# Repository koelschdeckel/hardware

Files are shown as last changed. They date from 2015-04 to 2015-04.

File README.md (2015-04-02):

Introduction
============

^^dkl is an Open Source hardware project that is being developed in
cooperation between the City of Cologne and Press Any Key UG. The
platform is intended to bridge the gap between devices similar to
Arduino, which allow physical access to sensors via electronic protocols
and device like Raspberry Pi that allow comfortable programming and
access to higher level facilities like Ethernet, USB and Bluetooth at
the cost of system complexity.

The system is intended to be used with applications that require
immediate interaction with the physical world, but need to interact with
the Internet or user devices. Furthermore, technical expertise required
to customise and operate the platform should be reduced to a minimum.

[Find out more](http://koelschdeckel.github.io/)

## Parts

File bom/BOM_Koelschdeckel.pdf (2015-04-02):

BOM # | # Sparrow | Parts sparrow | Type | Value | Shape | Manuf | Model | Alt | Mouser # | DK #

Resistors
| 1 | 4 | R5, R6, R40, R41 | Resistor | 33Ω 1% | 0603 | Samsung | RC1608F330CS | Vishay CRCW060333R0FKEA, Rohm MCR03ERTF33R0 | 71-CRCW0603-33-E3 | 1276-4524-1-ND
| 2 | 4 | R17, R18, R19, R20 | Resistor | 49.9Ω 1% | 0603 | Samsung | RC1608F49R9CS | Vishay CRCW060349R9FKEA | 71-CRCW0603-49.9-E3 | 1276-3505-1-ND
| 3 | 2 | R14, R15 | Resistor | 330Ω | 0603 | Samsung | RC1608J331CS | Yageo RC0603JR-07330RL, Yageo AF0603FR-07330RL, Vishay CRCW0603330RFKEA | 71-CRCW0603-330-E3 | 311-330GRCT-ND
| 4 | 1 | R3 | Resistor | 806Ω | 0603 | Yageo | RC0603FR-07806RL | KOA RK73H1JTTD8060F | 660-RK73H1JTTD8060F | 311-806HRCT-ND
| 5 | 4 | R4, R43, R44, R45 | Resistor | 1K | 0603 | Samsung | RC1608J102CS | Vishay CRCW06031K00FKEA, KOA RK73H1JTTD1001F | 660-RK73H1JTTD1001F | 1276-5062-1-ND
| 6 | 5 | R21, R22, R23, R38, R39 | Resistor | 2.2K | 0603 | Samsung | RC1608J222CS | KOA RK73H1JTTD2201F, Vishay CRCW06032K20FKEA, Yageo RC0603JR-072K2L | 660-RK73H1JTTD2201F | 1276-5070-1-ND
| 7 | 9 | R30, R32, R42, R8, R9, R10, R11, R12, R13 | Resistor | 10K | 0603 | Samsung | RC1608J103CS | Yageo RC0603JR-0710KL, Voshay CRCW060310K0FKEA, KOA RK73H1JTTD1002F | 660-RK73H1JTTD1002F | 1276-5086-1-ND
| 8 | 1 | R7 | Resistor | 12K 1% | 0603 | Samsung | RC1608F123CS | Rohm MCR03ERTF1202, KOA RK73H1JTTD1212F, Vishay CRCW060312K1FKEA | 660-RK73H1JTTD1212F | 1276-4750-1-ND
| 9 | 1 | R16 | Resistor | 12.1K 1% | 0603 | Samsung | RC1608F1212CS | KOA RK73H1JTTD1212F, Vishay CRCW060312K1FKEA, Stackpole RMCF0603FT12K1 | 660-RK73H1JTTD1212F | 1276-4751-1-ND
| 10 | 1 | R26 | Resistor | 40.2K | 0603 | Samsung | RC1608F4022CS | Yageo RC0603FR-0740K2L, KOA RK73H1JTTD4022F, Vishay CRCW060340K2FKEB | 660-RK73H1JTTD4022F | 1276-4800-1-ND
| 11 | 11 | R24, R25, R27, R28, R29, R31, R33, R34, R35, R36, R37 | Resistor | 100K | 0603 | Samsung | RC1608J104CS | Yageo RC0603JR-07100KL, Vishay CRCW0603100KFKEA, KOA RK73H1JTTD1003F | 660-RK73H1JTTD1003F | 1276-5110-1-ND
| 12 | 3 | R1, R46, R47 | Resistor | 768K | 0603 | Yageo | RC0603FR-07768KL | KOA RK73H1JTTD7683F, Rohm MCR03ERTF7683, Vishay CRCW0603768KFKEA | 660-RK73H1JTTD7683F | 311-768KHRCT-ND
| 13 | 1 | R2 | Resistor | 2.4M | 0603 | Samsung | RC1608J245CS | KOA RK73B1JTTD245J, Vishay CRCW06032M40JNEA, Yageo RC0603JR-072M4L | 660-RK73B1JTTD245J | 1276-5143-1-ND

Capacitors

| 14 | 1 | C55 | Capacitor | 2.2p | 0402 | Samsung | CL05C2R2CB5NNNC | Johanson 500R07S2R2DV4T | 609-500R07S2R2DV4T | 1276-1271-1-ND
| 15 | 2 | C68, C69 | Capacitor | 9p | 0402 | Samsung | CL05C090DB5NNNC | Murata GRM1555C1H9R0CA01D | 81-GRM1555C1H9R0CA1D | 1276-1617-1-ND
| 16 | | | Capacitor | 9p | 0603 | Samsung | CL10C090DB8NNNC | TDK C1608C0G1H090C080AA | 810-C1608C0G1H090C | 1276-2143-1-ND
| 17 | 1 | C11 | Capacitor | 10p 5% | 0603 | Samsung | CL10C100JB8NCNC | Vishay VJ0603A100JXACW1BC | 77-VJ0603A100JXACBC | 1276-2154-1-ND
| 18 | 2 | C66, C67 | Capacitor | 12p | 0402 | Samsung | CL05C120JB5NNNC | Johanson 500R07S120KV4T | 609-500R07S120KV4T | 1276-1178-1-ND
| 19 | 4 | C2, C22, C23, C65 | Capacitor | 18p 5% | 0603 | Samsung | CL10C180JC8NNNC | Vishay VJ0603A180JXACW1BC | 77-VJ0603A180JXACBC | 1276-2210-1-ND
| 20 | 1 | C28 | Capacitor | 470p 5% | 0603 | Samsung | CL10C471JB8NCNC | Vishay VJ0603A471JXXCW1BC | 77-VJ0603A471JXXCBC | 1276-2302-1-ND
| 21 | 1 | C1 | Capacitor | 1n | 0402 | Samsung | CL05B102KB5NCNC | KOA X7R0402HTTP102K | 660-X7R0402HTTP102K | 1276-1492-1-ND
| 22 | 1 | C72 | Capacitor | 2.2n | 0402 | Samsung | CL05B222KB5NNNC | Vishay VJ0402Y222KXJCW1BC | 77-VJ0402Y222KXJCBC | 1276-1054-1-ND
| 23 | 3 | C24, C25, C26 | Capacitor | 10n | | Samsung | CL10B103KB8NCNC | Vishay VJ0603Y103KXAAC | 77-VJ0603Y103KXAAC | 1276-1921-1-ND
| 24 | 1 | C61 | Capacitor | 47n | 0402 | Samsung | CL05B473KP5NNNC | Vishay VJ0402Y473KXQCW1BC | 77-VJ0402Y473KXQCBC | 1276-1573-1-ND
| 25 | 3 | C62, C63, C64 | Capacitor | 100n | 0402 | Samsung | CL05A104KP5NNNC | Vishay VJ0402G104MXQPW1BC | 77-VJ0402G104MXQPBC | 1276-1022-1-ND
| 26 | 34 | C3, C4, C5, C6, C7, C12, C13, C14, C15, C16, C17, C18. C19, C20, C21, C30, C31, C32, C33, C34, C35, C36, C37. C38, C39, C43, C45, C47, C49, C54, C58, C70, C74, C75 | Capacitor | 100n | 0603 | Samsung | CL10B104KO8NNNC | Vishay VJ0603Y104JXJPW1BC | 77-VJ0603Y104JXJPBC | 1276-1005-1-ND
| 27 | 9 | C27, C52, C53, C56, C76, C77, C78, C79, C80 | Capacitor | 1u | 0603 | Samsung | CL10B105KP8NNNC | AVX 0603YD105KAT2A | 581-0603YD105K | 1276-1946-1-ND

| 28 | 3 | C8, C9, C10 | Capacitor | 4.7u | 0603 | Samsung | CL10B475KQ8NQNC | Murata GRM188R60J475ME19D | 81-GRM188R60J475ME9D | 1276-2087-1-ND
| 29 | 5 | C29, C42, C44, C46, C48 | Capacitor | 10u | 0603 | Samsung | CL10A106MQ8NNNC | AVX 06036D106MAT2A | 581-06036D106MAT2A | 1276-1119-1-ND
| 30 | 2 | C40, C41 | Capacitor | 22u 6.3V | 0603 | Samsung | CL10A226MQ8NRNC | Murata GRM188R60J226MEA0D, TDK C1608X5R0J226M080AC | 810-C1608X5R0J226M | 1276-1193-1-ND
| 31 | 2 | C57, C59 | Capacitor | 22u 10V | 0805 | Samsung | CL21A226MPQNNNE | TDK C2012X5R1A226M125AB | 810-C2012X5R1A226M-3 | 1276-2910-1-ND
| 32 | 2 | C50, C51 | Capacitor | 47u 6.3V | 0805 | Samsung | CL21A476MQCLRNC | Taiyo Yuden JMK212BJ476MG-T | 963-JMK212BJ476MG-T | 1276-2420-1-ND
| 33 | 1 | C60 | Capacitor | 150u 10V | 1210_POL | AVX | TLNT157M010R1500 | AVX TLJB157M010R0500 | 581-TLNT157M010R | 478-3349-1-ND

Inductors
| 34 | 1 | L5 | Inductor | 2.2n | 0402 | Taiyo Yuden | HK10052N2S-T | Taiyo Yuden HK10052N2S-T, Panasonic ELJ-RF2N2ZFB, TDK MLG1005S2N2S | 963-HK10052N2S-T | 587-1503-1-ND
| 35 | 1 | L7 | Inductor | 2.2u 2.2Arms, 3A sat | 40x40 | Laird | TYS40302R2N-10 | Bourns SRN4018-2R2M, Taiyo Yuden NRS4018T2R2MDGJ | 963-NRS4018T2R2MDGJ | 240-2697-1-ND
| 36 | 1 | L1 | Inductor | 10u 1A | 40x40 | Taiyo Yuden | NRS4018T100MDGJ | | 963-NRS4018T100MDGJ | 587-2886-1-ND

Diodes
| 37 | 5 | D1, D2, D3, D4, D5 | Diode | 2A 30V Schottky | SOD123/ SOD123FL | ON Semi | MBR230LSFT1 | Comchip CDBMT240-HF | 863-MBR230LSFT1G | MBR230LSFT1GOSCT-ND

LEDs
| 38 | 4 | LED1, LED2, LED3, LED4 | LED | any color, 100mcd min | 0603_POL | Vishay | VLMY1300-GS08 (yellow) | Osram LS Q976-NR-1 | 78-VLMY1300-GS08 | 475-2512-1-ND

ICs

| 39 | 1 | IC1 | IC | LAN8720A | QFN24-0.5 | SMSC/Microchip | LAN8720A/ LAN8720AI | | 886-LAN8720A-CP | LAN8720A-CP-CT-ND
| 40 | 1 | IC2 | IC | TLV320AIC3100 | QFN32-0.5 | TI | TLV320AIC3100IRHBR/T | | 595-V320AIC3100IRHBT | 296-25494-1-ND
| 41 | 1 | IC3 | IC | TPS2500 | SON10-0.5 | TI | TPS2500DRCT | | 595-TPS2500DRCT | 296-32462-1-ND
| 42 | 5 | IC4, IC5, IC6, IC7, IC8 | IC | AAT4280A | SC70JW-8 | Skyworks | AAT4280A | | 873-AAT4280AIJS-2-T1 | 863-1480-1-ND
| 43 | 1 | IC9 | IC | FXMA108 | DFN20 | Fairchild | FXMA108 | | 512-FXMA108BQX | FXMA108BQXFSCT-ND
| 44 | 1 | MCU | IC | NXP1837 | QFP144-0.5 | NXP | LPC1837JBD144E | | 771-LPC1837JBD144E | LPC1837JBD144E-ND
| 45 | 1 | MCU1 | IC | NRF51822 | QFN48-0.4 | Nordic Semi | NRF51822QFAA | | 949-NRF51822-QFAA-R7
| 46 | | | IC | PN532 | QFN40 | NXP | PN5321A3HN/C106;55 | | 771-PN5321A3HNC106 | 568-8600-ND
| 47 | 1 | PWR1 | IC | LTC4080 | DFN10 | Linear | LTC4080 | LTC4081 | | LTC4081EDD#PBF-ND

Modules

| 48 | 1 | WIFI | Module | CC3000 | | TI | CC3000MOD | | 595-CC3000MOD | 296-35512-1-ND

Clocks
| 49 | 2 | X1, X3 | Crystal | 32.768KHz 12.5pF | 1206 | Abracon | ABS07 | TXC 9HT10-32.768KAZF-T, Citizen CM315D32768DZFT | 717-9HT10-32.768KAZF | 300-8814-1-ND
| 50 | 1 | X2 | Crystal | 12MHz 10pF 40ppm | 3.2 x 2.5 | AVX | CX3225GB12000P0HPQC C | ABM8G-12.000MHZ-4Y-T3 | 581-CX3225GB12PHPQCC | 535-10901-1-ND
| 51 | 1 | X5 | Crystal | 16MHz 8pF 40ppm | 2.5 x 2.0 | AVX | CX2520DB16000D0GEJC C | | 581-CX2520DB16DGEJCC | 1253-1122-1-ND
| 52 | | | Crystal | 27.12MHz 10pF 20ppm | 5 x 3.2 | TXC | 7B-27.120MEEQ-T | | | 887-1309-1-ND
| 53 | 1 | X4 | Oscillator | 50MHz | 2.5 x 2.0 | SiLabs | 501AAA50M0000DAG | SITime SiT8103AI-13-33E-50.00000X | 788-8103I-333E50X | 336-2981-ND

RF

| 54 | 2 | ANT1, ANT2 | Antenna | 2.4GHz | 1206 | Abracon | AMCA31-2R450G-S1F | | 815-CA312R450GS1FT | 535-12386-1-ND
| 55 | 1 | BAL1 | Balun | for NRF51822 | WLCSP5 | ST | BALF-NRF01D3 | BAL-NRF01D3 (worse) | 511-BAL-NRF01D3 | 497-13637-1-ND

Mechanical

| 56 | 2 | !PGM, RESET | Button | CK-KMR2 | | CK | KMR2xx | | 611-KMR211G-LFS | CKN10272CT-ND
| 57 | 1 | 5VDC_IN | Connector | Barrel 5.5/2.1 2A | | CUI | PJ 102AH | | | CP-102AH-ND
| 58 | 1 | BATT | Connector | 2mm LiPo/Li-Ion | | JST | PH-H | | | 455-1749-1-ND
| 59 | 1 | ETH | Connector | RJ45-Mag-LEDs | | WIZnet | RB1-125BAG1A | | 950-RB1-125BAG1A | 1278-1011-ND
| 60 | 1 | HEADPHONE | Connector | 3.5mm stereo | | CUI | SJ 3523 | Switchcraft 35RASMT2BHNTRX | 502-35RASMT2BHNTRX | CP-3523SJCT-ND

61 | 1 | SD_CARD | Connector | SD card holder | Amphenol | 101_00313 | 523-101-00313-68-02
62 | 1 | USB1 | Connector | Micro USB-B | FCI | 10104110-0001LF | 649-10104110-0001LF
63 | 1 | USB0 | Connector | Micro USB-AB | FCI | 10104111-0001LF | 649-10104111-0001LF

ARM DEBUGs

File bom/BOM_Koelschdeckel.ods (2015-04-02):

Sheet: Tabelle1
Order Master |  | 5
Order NFC |  | 5
Category | BOM # | # Sparrow | # NFC | Parts sparrow | check | Parts NFC | check | Type | Value | Shape | # needed | # have | Manuf | Model | Alt | Mouser # | Mouser € | Mouser @ | DK # | DK € | DK @ | Schukat # | Schukat € | Schukat @ | Order source | Order # | Ordered | Mouser € | DK € | Schukat € | Remarks | Received | € per sparrow |  | Mouser order table | Mouser order table | DK order table | DK order table
Resistors
 | 1 |  | 2 |  | ✓ | R17,R18 | ✓ | Resistor | 1.5Ω | 0603 | 10 |  | Samsung | RC1608J1R5CS | KOA RK73H1JTTD1R50F, Yageo RC0603JR-071R5L | 660-RK73H1JTTD1R50F | 0,006 | 100 | 1276-4994-1-ND | 0,0036 | 100 |  |  |  | DK | 100 | DK + |  | 0,36 |  |  | ✓ | 0 | 0,0072 |  |  | 100 | 1276-4994-1-ND
 | 2 | 4 |  | R5, R6, R40, R41 | ✓ |  | ✓ | Resistor | 33Ω 1% | 0603 | 20 | yeah! | Samsung | RC1608F330CS | Vishay CRCW060333R0FKEA, Rohm MCR03ERTF33R0 | 71-CRCW0603-33-E3 | 0,008 | 100 | 1276-4524-1-ND | 0,0046 | 100 |  |  |  | DK | 100 | Bestand |  | 0,46 |  |  | (✓) | 0,0184 | 0
 | 3 | 4 |  | R17, R18, R19, R20 | ✓ |  | ✓ | Resistor | 49.9Ω 1% | 0603 | 20 |  | Samsung | RC1608F49R9CS | Vishay CRCW060349R9FKEA | 71-CRCW0603-49.9-E3 | 0,008 | 100 | 1276-3505-1-ND | 0,0046 | 100 |  |  |  | DK | 100 | DK + |  | 0,46 |  |  | ✓ | 0,0184 | 0 |  |  | 100 | 1276-3505-1-ND
 | 4 | 2 |  | R14, R15 | ✓ |  | ✓ | Resistor | 330Ω | 0603 | 10 |  | Samsung | RC1608J331CS | Yageo RC0603JR-07330RL, Yageo AF0603FR-07330RL, Vishay CRCW0603330RFKEA | 71-CRCW0603-330-E3 | 0,008 | 100 | 311-330GRCT-ND | 0,0036 | 100 |  |  |  | DK | 100 | DK + |  | 0,36 |  |  | ✓ | 0,0072 | 0 |  |  | 100 | 311-330GRCT-ND
 | 5 | 1 | 1 | R3 | ✓ | R3 | ✓ | Resistor | 806Ω | 0603 | 10 |  | Yageo | RC0603FR-07806RL | KOA RK73H1JTTD8060F | 660-RK73H1JTTD8060F | 0,006 | 100 | 311-806HRCT-ND | 0,0046 | 100 |  |  |  | DK | 100 | DK + |  | 0,46 |  |  | ✓ | 0,0046 | 0,0046 |  |  | 100 | 311-806HRCT-ND
 | 6 | 4 | 6 | R4, R43, R44, R45 | ✓ | R4, R13, R14, R15, R19, R21 | ✓ | Resistor | 1K | 0603 | 50 |  | Samsung | RC1608J102CS | Vishay CRCW06031K00FKEA, KOA RK73H1JTTD1001F | 660-RK73H1JTTD1001F | 0,006 | 100 | 1276-5062-1-ND | 0,0036 | 100 | RL0603K001-1 | 0,00119 | 5000 | Schukat | 5000 | Schukat |  |  | 5,95 | Digikey ist pro Rolle günstiger als Schukat, aber Schukat hat 1% statt 5% Toleranz | ✓ | 0,00476 | 0,00714
 | 7 |  | 1 |  | ✓ | R16 | ✓ | Resistor | 1.6K | 0603 | 5 |  | Samsung | RC1608J162CS | KOA RK73H1JTTD1601F, Vishay CRCW06031K60FKEA, Yageo RC0603JR-071K6L | 660-RK73H1JTTD1601F | 0,006 | 100 | 1276-5067-1-ND | 0,0036 | 100 |  |  |  | DK | 100 | DK + |  | 0,36 |  |  | ✓ | 0 | 0,0036 |  |  | 100 | 1276-5067-1-ND
 | 8 |  | 3 |  | ✓ | R10, R11, R16 | ✓ | Resistor | 2K | 0603 | 15 |  | Samsung | RC1608J202CS | Vishay CRCW06032K00FKEA, KOA RK73H1JTTD2001F, Yageo RC0603JR-072KL | 660-RK73H1JTTD2001F | 0,006 | 100 | 1276-5069-1-ND | 0,0036 | 100 |  |  |  | DK | 100 | DK + |  | 0,36 |  |  | ✓ | 0 | 0,0108 |  |  | 100 | 1276-5069-1-ND
 | 9 | 5 |  | R21, R22, R23, R38, R39 | ✓ |  | ✓ | Resistor | 2.2K | 0603 | 25 |  | Samsung | RC1608J222CS | KOA RK73H1JTTD2201F, Vishay CRCW06032K20FKEA, Yageo RC0603JR-072K2L | 660-RK73H1JTTD2201F | 0,006 | 100 | 1276-5070-1-ND | 0,0036 | 100 | RL0603K002.2-1 | 0,00119 | 5000 | Schukat | 5000 | Schukat |  |  | 5,95 |  | ✓ | 0,00595 | 0
 | 10 | 9 | 6 | R30, R32, R42, R8, R9, R10, R11, R12, R13 | ✓ | R5, R6, R7, R9, R12, R34 | ✓ | Resistor | 10K | 0603 | 75 | yeah! | Samsung | RC1608J103CS | Yageo RC0603JR-0710KL, Voshay CRCW060310K0FKEA, KOA RK73H1JTTD1002F | 660-RK73H1JTTD1002F | 0,006 | 100 | 1276-5086-1-ND | 0,0036 | 100 | RL0603K010-1 | 0,00119 | 5000 | Schukat | 5000 | Bestand |  |  | 5,95 |  | (✓) | 0,01071 | 0,00714
 | 11 | 1 |  | R7 | ✓ |  | ✓ | Resistor | 12K 1% | 0603 | 5 |  | Samsung | RC1608F123CS | Rohm MCR03ERTF1202, KOA RK73H1JTTD1212F, Vishay CRCW060312K1FKEA | 660-RK73H1JTTD1212F | 0,006 | 100 | 1276-4750-1-ND | 0,0046 | 100 |  |  |  | DK | 100 | DK + |  | 0,46 |  |  | ✓ | 0,0046 | 0 |  |  | 100 | 1276-4750-1-ND
 | 12 | 1 |  | R16 | ✓ |  | ✓ | Resistor | 12.1K 1% | 0603 | 5 |  | Samsung | RC1608F1212CS | KOA RK73H1JTTD1212F, Vishay CRCW060312K1FKEA, Stackpole RMCF0603FT12K1 | 660-RK73H1JTTD1212F | 0,006 | 100 | 1276-4751-1-ND | 0,0046 | 100 |  |  |  | DK | 100 | DK + |  | 0,46 |  |  | ✓ | 0,0046 | 0 |  |  | 100 | 1276-4751-1-ND
 | 13 | 1 |  | R26 | ✓ |  | ✓ | Resistor | 40.2K | 0603 | 5 |  | Samsung | RC1608F4022CS | Yageo RC0603FR-0740K2L, KOA RK73H1JTTD4022F, Vishay CRCW060340K2FKEB | 660-RK73H1JTTD4022F | 0,006 | 100 | 1276-4800-1-ND | 0,0046 | 100 |  |  |  | DK | 100 | DK + |  | 0,46 |  |  | ✓ | 0,0046 | 0 |  |  | 100 | 1276-4800-1-ND
 | 14 | 11 |  | R24, R25, R27, R28, R29, R31, R33, R34, R35, R36, R37 | ✓ |  | ✓ | Resistor | 100K | 0603 | 55 |  | Samsung | RC1608J104CS | Yageo RC0603JR-07100KL, Vishay CRCW0603100KFKEA, KOA RK73H1JTTD1003F | 660-RK73H1JTTD1003F | 0,006 | 100 | 1276-5110-1-ND | 0,0036 | 100 | RL0603K100-1 | 0,00119 | 5000 | Schukat | 5000 | Schukat |  |  | 5,95 |  | ✓ | 0,01309 | 0
 | 15 | 3 | 1 | R1, R46, R47 | ✓ | R1 | ✓ | Resistor | 768K | 0603 | 20 |  | Yageo | RC0603FR-07768KL | KOA RK73H1JTTD7683F, Rohm MCR03ERTF7683, Vishay CRCW0603768KFKEA | 660-RK73H1JTTD7683F | 0,006 | 100 | 311-768KHRCT-ND | 0,0048 | 100 |  |  |  | DK | 100 | DK + |  | 0,48 |  |  | ✓ | 0,0144 | 0,0048 |  |  | 100 | 311-768KHRCT-ND
 | 16 | 1 | 1 | R2 | ✓ | R2 | ✓ | Resistor | 2.4M | 0603 | 10 |  | Samsung | RC1608J245CS | KOA RK73B1JTTD245J, Vishay CRCW06032M40JNEA, Yageo RC0603JR-072M4L | 660-RK73B1JTTD245J | 0,003 | 100 | 1276-5143-1-ND | 0,0036 | 100 |  |  |  | Mouser | 100 | Mouser + | 0,3 |  |  |  | ✓ | 0,003 | 0,003 | 100 | 660-RK73B1JTTD245J
Capacitors |  |  |  |  |  |  | ✓ |  |  |  |  |  |  |  |  |  |  |  |  |  |  |  |  |  |  |  |  |  |  |  |  |  | 0 | 0
 | 17 | 1 |  | C55 | ✓ |  | ✓ | Capacitor | 2.2p | 0402 | 5 |  | Samsung | CL05C2R2CB5NNNC | Johanson 500R07S2R2DV4T | 609-500R07S2R2DV4T | 0,016 | 1 | 1276-1271-1-ND | 0,0062 | 100 |  |  |  | DK | 100 | DK + |  | 0,62 |  |  | ✓ | 0,0062 | 0 |  |  | 100 | 1276-1271-1-ND
 | 18 | 2 |  | C68, C69 | ✓ |  | ✓ | Capacitor | 9p | 0402 | 10 |  | Samsung | CL05C090DB5NNNC | Murata GRM1555C1H9R0CA01D | 81-GRM1555C1H9R0CA1D | 0,008 | 100 | 1276-1617-1-ND | 0,0076 | 100 |  |  |  | DK | 100 | DK + |  | 0,76 |  |  | ✓ | 0,0152 | 0 |  |  | 100 | 1276-1617-1-ND
 | 19 |  | 2 |  |  | C68, C69 | ✓ | Capacitor | 9p | 0603 | 10 |  | Samsung | CL10C090DB8NNNC | TDK C1608C0G1H090C080AA | 810-C1608C0G1H090C | 0,01 | 100 | 1276-2143-1-ND | 0,0153 | 100 |  |  |  | Mouser | 100 | Mouser + | 1 |  |  |  | ✓ | 0 | 0,02 | 100 | 810-C1608C0G1H090C
 | 20 | 1 | 3 | C11 | ✓ | C11, C31, C39 | ✓ | Capacitor | 10p 5% | 0603 | 20 |  | Samsung | CL10C100JB8NCNC | Vishay VJ0603A100JXACW1BC | 77-VJ0603A100JXACBC | 0,032 | 100 | 1276-2154-1-ND | 0,0036 | 100 |  |  |  | DK | 100 | DK + |  | 0,36 |  |  | ✓ | 0,0036 | 0,0108 |  |  | 100 | 1276-2154-1-ND
 | 21 | 2 |  | C66, C67 | ✓ |  | ✓ | Capacitor | 12p | 0402 | 10 | yeah! | Samsung | CL05C120JB5NNNC | Johanson 500R07S120KV4T | 609-500R07S120KV4T | 0,016 | 1 | 1276-1178-1-ND | 0,0047 | 100 |  |  |  | DK | 100 | Bestand |  | 0,47 |  |  | (✓) | 0,0094 | 0
 | 22 |  | 6 |  | ✓ | C1, C2, C22, C23, C66, C67 | ? | Capacitor | 12p 5% | 0603 | 30 |  | Samsung | CL10C120JC8NNNC | Vishay VJ0603A120JXACW1BC | 77-VJ0603A120JXACBC | 0,032 | 100 | 1276-2177-1-ND | 0,0091 | 100 |  |  |  | DK | 100 | DK + |  | 0,91 |  |  | ✓ | 0 | 0,0546 |  |  | 100 | 1276-2177-1-ND
 | 23 |  | 4 |  | ✓ | C1, C2, C22, C23, C66, C67 | ? | Capacitor | 16p 5% | 0603 | 20 |  | Samsung | CL10C160JB8NNNC | Murata GCM1885C2A160JA16D | 81-GCM1885C2A160JA6D | 0,02 | 100 | 1276-2204-1-ND | 0,02450 | 100 |  |  |  | DK | 100 | DK + |  | 2,45 |  |  | ✓ | 0 | 0,098 |  |  | 100 | 1276-2204-1-ND
 | 24 | 4 |  | C2, C22, C23, C65 | ✓ |  | ✓ | Capacitor | 18p 5% | 0603 | 20 | yeah! | Samsung | CL10C180JC8NNNC | Vishay VJ0603A180JXACW1BC | 77-VJ0603A180JXACBC | 0,032 | 100 | 1276-2210-1-ND | 0,0072 | 100 |  |  |  | DK | 100 | Bestand |  | 0,72 |  |  | (✓) | 0,0288 | 0
 | 25 |  | 2 |  | ✓ | C45, C48 | ✓ | Capacitor | 22p 5% | 0603 | 10 |  | Samsung | CL10C220JB8NCNC | Vishay VJ0603A220JXACW1BC, TDK C1608C0G1H220J080AA | 77-VJ0603A220JXACBC | 0,032 | 100 | 1276-2227-1-ND | 0,0036 | 100 |  |  |  | DK | 100 | DK + |  | 0,36 |  | Ersatzmodell bestellt | ✓ | 0 | 0,0072 |  |  | 100 | 1276-2227-1-ND
 | 26 |  | 1 |  | ✓ | C37 | ✓ | Capacitor | 27p 5% | 0603 | 5 |  | Samsung | CL10C270JB8NCNC | Vishay VJ0603A270JXACW1BC | 77-VJ0603A270JXACBC | 0,032 | 100 | 1276-2248-1-ND | 0,0036 | 100 |  |  |  | DK | 100 | DK + |  | 0,36 |  |  | ✓ | 0 | 0,0036 |  |  | 100 | 1276-2248-1-ND
 | 27 |  | 2 |  | ✓ | C37, C38 | ✓ | Capacitor | 47p 5% | 0603 | 10 |  | Samsung | CL10C470JB8NCNC | Vishay VJ0603A470JXACW1BC | 77-VJ0603A470JXACBC | 0,032 | 100 | 1276-2296-1-ND | 0,0049 | 100 |  |  |  | DK | 100 | DK + |  | 0,49 |  |  | ✓ | 0 | 0,0098 |  |  | 100 | 1276-2296-1-ND
 | 28 |  | 1 |  | ✓ | C44 | ✓ | Capacitor | 56p 5% | 0603 | 5 |  | Samsung | CL10C560JB8NNNC | Vishay VJ0603A560JXACW1BC | 77-VJ0603A560JXACBC | 0,032 | 100 | 1276-1197-1-ND | 0,0092 | 100 |  |  |  | DK | 100 | DK + |  | 0,92 |  |  | ✓ | 0 | 0,0092 |  |  | 100 | 1276-1197-1-ND
 | 29 |  | 3 |  | ✓ | C34, C43, C50 | ✓ | Capacitor | 100p 5% | 0603 | 15 |  | Samsung | CL10C101JB8NCNC | Vishay VJ0603A101JXACW1BC | 77-VJ0603A101JXACBC | 0,032 | 100 | 1276-2163-1-ND | 0,0036 | 100 |  |  |  | DK | 100 | DK + |  | 0,36 |  |  | ✓ | 0 | 0,0108 |  |  | 100 | 1276-2163-1-ND
 | 30 |  | 3 |  | ✓ | C32, C46, C47 | ✓ | Capacitor | 220p 5% | 0603 | 15 |  | Samsung | CL10C221JB8NCNC | Vishay VJ0603A221JXBPW1BC | 77-VJ0603A221JXBPBC | 0,01 | 100 | 1276-2234-1-ND | 0,0049 | 100 |  |  |  | DK | 100 | DK + |  | 0,49 |  | Ersatzmodell bestellt | ✓ | 0 | 0,0147 |  |  | 100 | 1276-2234-1-ND
 | 31 | 1 |  | C28 | ✓ |  | ✓ | Capacitor | 470p 5% | 0603 | 5 |  | Samsung | CL10C471JB8NCNC | Vishay VJ0603A471JXXCW1BC | 77-VJ0603A471JXXCBC | 0,018 | 100 | 1276-2302-1-ND | 0,01210 | 100 |  |  |  | DK | 100 | DK + |  | 1,21 |  | Ersatzmodell bestellt | ✓ | 0,0121 | 0 |  |  | 100 | 1276-2302-1-ND
 | 32 |  | 2 |  | ✓ | C30, C33 | ✓ | Capacitor | 680p 5% | 0603 | 10 |  | Samsung | CL10C681JB8NFNC | Vishay VJ0603Y681JXBCW1BC | 77-VJ0603Y681JXBCBC | 0,025 | 100 | 1276-2329-1-ND | 0,01210 | 100 |  |  |  | DK | 100 | DK + |  | 1,21 |  |  | ✓ | 0 | 0,0242 |  |  | 100 | 1276-2329-1-ND
 | 33 | 1 | 1 | C1 | ✓ | C65 | ✓ | Capacitor | 1n | 0402 | 10 | yeah! | Samsung | CL05B102KB5NCNC | KOA X7R0402HTTP102K | 660-X7R0402HTTP102K | 0,008 | 1 | 1276-1492-1-ND | 0,0041 | 100 |  |  |  | DK | 100 | Bestand |  | 0,41 |  |  | (✓) | 0,0041 | 0,0041
 | 34 |  | 1 |  | ✓ | C42 | ✓ | Capacitor | 1n 5% | 0603 | 5 |  | Samsung | CL10C102JB8NNNC | Vishay VJ0603Y102JXBCW1BC | 77-VJ0603Y102JXBCBC | 0,025 | 100 | 1276-1091-1-ND | 0,01260 | 100 |  |  |  | DK | 100 | DK + |  | 1,26 |  |  | ✓ | 0 | 0,0126 |  |  | 100 | 1276-1091-1-ND
 | 35 |  | 2 |  | ✓ | C28, C29 | ✓ | Capacitor | 1.2n 5% | 0603 | 10 |  | Samsung | CL10C122JB8NNNC | Murata GRM1885C1E122JA01D | 81-GRM1885C1E122JA1D | 0,022 | 100 | 1276-2184-1-ND | 0,0306 | 100 |  |  |  | Mouser | 100 | Mouser + | 2,2 |  |  |  | ✓ | 0 | 0,044 | 100 | 81-GRM1885C1E122JA1D
 | 36 |  | 2 |  | ✓ | C26, C27 | ✓ | Capacitor | 1.5n 5% | 0603 | 10 |  | Samsung | CL10C152JB8NNNC | Vishay VJ0603Y152JXAAC | 77-VJ0603Y152JXAAC | 0,023 | 100 | 1276-2203-1-ND | 0,0298 | 100 |  |  |  | Mouser | 100 | Mouser + | 2,3 |  |  |  | ✓ | 0 | 0,046 | 100 | 77-VJ0603Y152JXAAC
 | 37 | 1 | 1 | C72 | ✓ | C72 | ✓ | Capacitor | 2.2n | 0402 | 10 | yeah! | Samsung | CL05B222KB5NNNC | Vishay VJ0402Y222KXJCW1BC | 77-VJ0402Y222KXJCBC | 0,026 | 100 | 1276-1054-1-ND | 0,0052 | 100 |  |  |  | DK | 100 | Bestand |  | 0,52 |  |  | (✓) | 0,0052 | 0,0052
 | 38 | 3 | 5 | C24, C25, C26 | ✓ | C3, C7, C13, C15, C17 | ✓ | Capacitor | 10n |  | 40 |  | Samsung | CL10B103KB8NCNC | Vishay VJ0603Y103KXAAC | 77-VJ0603Y103KXAAC | 0,024 | 100 | 1276-1921-1-ND | 0,0036 | 100 | CL10B103KB8NNNC | 0,0014 | 4000 | Schukat | 4000 | Schukat |  |  | 5,6 |  | ✓ | 0,0042 | 0,007
 | 39 | 1 | 1 | C61 | ✓ | C61 | ✓ | Capacitor | 47n | 0402 | 10 | yeah! | Samsung | CL05B473KP5NNNC | Vishay VJ0402Y473KXQCW1BC | 77-VJ0402Y473KXQCBC | 0,046 | 100 | 1276-1573-1-ND | 0,0052 | 100 |  |  |  | Mouser | 100 | Bestand | 4,6 |  |  |  | (✓) | 0,046 | 0,046
 | 40 | 3 |  | C62, C63, C64 | ✓ |  | ✓ | Capacitor | 100n | 0402 | 15 | yeah! | Samsung | CL05A104KP5NNNC | Vishay VJ0402G104MXQPW1BC | 77-VJ0402G104MXQPBC | 0,046 | 100 | 1276-1022-1-ND | 0,0044 | 100 |  |  |  | DK | 100 | Bestand |  | 0,44 |  |  | (✓) | 0,0132 | 0
 | 41 | 34 | 11 | C3, C4, C5, C6, C7, C12, C13, C14, C15, C16, C17, C18. C19, C20, C21, C30, C31, C32, C33, C34, C35, C36, C37. C38, C39, C43, C45, C47, C49, C54, C58, C70, C74, C75 | ✓ | C5, C19, C20, C21, C24, C35, C36, C41, C62, C63, C64 | ✓ | Capacitor | 100n | 0603 | 225 |  | Samsung | CL10B104KO8NNNC | Vishay VJ0603Y104JXJPW1BC | 77-VJ0603Y104JXJPBC | 0,015 | 100 | 1276-1005-1-ND | 0,0068 | 100 | CL10B104KO8NNNC | 0,0018 | 4000 | Schukat | 4000 | Schukat |  |  | 7,2 |  | ✓ | 0,0612 | 0,0198
 | 42 | 9 | 2 | C27, C52, C53, C56, C76, C77, C78, C79, C80 | ✓ | C76, C77 | ✓ | Capacitor | 1u | 0603 | 55 | yeah! | Samsung | CL10B105KP8NNNC | AVX 0603YD105KAT2A | 581-0603YD105K | 0,026 | 100 | 1276-1946-1-ND | 0,0149 | 100 | CL10B105KO8NNNC | 0,0053 | 4000 | Schukat | 4000 | Bestand |  |  | 21,2 |  | (✓) | 0,0477 | 0,0106
 | 43 |  | 5 |  | ✓ | C4, C12, C14, C16, C18 | ✓ | Capacitor | 2.2u | 0603 | 25 |  | Samsung | CL10B225KP8NNNC | TDK C1608X5R0J225K080AB, Taiyo Yuden JMK107BJ225KAHT | 810-C1608X5R0J225K | 0.03 | 100 | 1276-1134-1-ND | 0,0434 | 100 |  |  |  | Mouser | 100 | Mouser + | 3 |  |  |  | ✓ | 0 | 0,15 | 100 | 810-C1608X5R0J225K
 | 44 | 3 | 4 | C8, C9, C10 | ✓ | C6, C8, C9, C10 | ✓ | Capacitor | 4.7u | 0603 | 35 | yeah! | Samsung | CL10B475KQ8NQNC | Murata GRM188R60J475ME19D | 81-GRM188R60J475ME9D | 0.025 | 100 | 1276-2087-1-ND | 0.027 | 100 |  |  |  | Mouser | 100 | Bestand | 2,5 |  |  |  | (✓) | 0,075 | 0,1
 | 45 | 5 | 1 | C29, C42, C44, C46, C48 | ✓ | C25 | ✓ | Capacitor | 10u | 0603 | 30 | yeah! | Samsung | CL10A106MQ8NNNC | AVX 06036D106MAT2A | 581-06036D106MAT2A | 0.0616 | 50 | 1276-1119-1-ND | 0,102 | 10 |  |  |  | DK | 50 | Bestand |  | 5,1 |  |  | (✓) | 0,51 | 0,102
 | 46 | 2 |  | C40, C41 | ✓ |  | ✓ | Capacitor | 22u 6.3V | 0603 | 10 |  | Samsung | CL10A226MQ8NRNC | Murata GRM188R60J226MEA0D, TDK C1608X5R0J226M080AC | 810-C1608X5R0J226M | 0,163 | 10 | 1276-1193-1-ND | 0.267 | 10 |  |  |  | Mouser | 20 | Mouser + | 3,26 |  |  |  | ✓ | 0,326 | 0 | 20 | 810-C1608X5R0J226M
 | 47 | 2 |  | C57, C59 | ✓ |  | ✓ | Capacitor | 22u 10V | 0805 | 10 |  | Samsung | CL21A226MPQNNNE | TDK C2012X5R1A226M125AB | 810-C2012X5R1A226M-3 | 0.221 | 10 | 1276-2910-1-ND | 0.275 | 10 |  |  |  | Mouser | 20 | Mouser + | 4,42 |  |  |  | ✓ | 0,442 | 0 | 20 | 810-C2012X5R1A226M-3
 | 48 | 2 |  | C50, C51 | ✓ |  | ✓ | Capacitor | 47u 6.3V | 0805 | 10 |  | Samsung | CL21A476MQCLRNC | Taiyo Yuden JMK212BJ476MG-T | 963-JMK212BJ476MG-T | 0.59 | 10 | 1276-2420-1-ND | 0.4148 | 25 |  |  |  | DK | 25 | DK + |  | 10,37 |  |  | ✓ | 0,8296 | 0 |  |  | 25 | 1276-2420-1-ND
 | 49 | 1 |  | C60 | ✓ |  | ✓ | Capacitor | 150u 10V | 1210_POL | 5 |  | AVX | TLNT157M010R1500 | AVX TLJB157M010R0500 | 581-TLNT157M010R | 1,69 | 1 | 478-3349-1-ND | 1.668 | 10 |  |  |  | DK | 10 | DK + |  | 16,68 |  |  | ✓ | 1,668 | 0 |  |  | 10 | 478-3349-1-ND
Inductors |  |  |  |  |  |  |  |  |  |  |  |  |  |  |  |  |  |  |  |  |  |  |  |  |  |  |  |  |  |  |  |  | 0 | 0
 | 50 | 1 |  | L5 | ✓ |  | ✓ | Inductor | 2.2n | 0402 | 5 |  | Taiyo Yuden | HK10052N2S-T | Taiyo Yuden HK10052N2S-T, Panasonic ELJ-RF2N2ZFB, TDK MLG1005S2N2S | 963-HK10052N2S-T | 0.036 | 10 | 587-1503-1-ND | 0.038 | 10 |  |  |  | Mouser | 10 | Mouser + | 0,36 |  |  |  | ✓ | 0,036 | 0 | 10 | 963-HK10052N2S-T
 | 51 |  | 1 |  | ✓ | L2 | ✓ | Inductor | 150n 150mA | 0603 | 5 |  | Taiyo Yuden | LK1608R15K-T |  | 963-LK1608R15K-T | 0.101 | 10 | 587-1559-1-ND | 0.065 | 10 |  |  |  | DK | 10 | DK + |  | 0,65 |  |  | ✓ | 0 | 0,065 |  |  | 10 | 587-1559-1-ND
 | 52 |  | 1 |  | ✓ | L3 | ✓ | Inductor | 330n 150mA | 0603 | 5 |  | Taiyo Yuden | HK1608R33J-T | Bourns CS160808-R33K | 963-HK1608R33J-T | 0.063 | 10 | 587-1563-1-ND | 0.065 | 10 |  |  |  | Mouser | 10 | Mouser + | 0,63 |  |  |  | ✓ | 0 | 0,063 | 10 | 963-HK1608R33J-T
 | 53 |  | 2 |  | ✓ | L5, L6 | ✓ | Inductor | 560n 100mA | 0603 | 10 |  | TDK | MLF1608DR56M |  | 810-MLF1608DR56M | 0,09 | 10 | 445-6242-1-ND | 0,115 | 10 |  |  |  | Mouser | 20 | Mouser + | 1,8 |  |  |  | ✓ | 0 | 0,18 | 20 | 810-MLF1608DR56M
 | 54 | 1 |  | L7 | ✓ |  | ✓ | Inductor | 2.2u 2.2Arms, 3A sat | 40x40 | 5 |  | Laird | TYS40302R2N-10 | Bourns SRN4018-2R2M, Taiyo Yuden NRS4018T2R2MDGJ | 963-NRS4018T2R2MDGJ | 0.258 | 10 | 240-2697-1-ND | 0.328 | 10 |  |  |  | Mouser | 10 | Mouser + | 2,58 |  |  |  | ✓ | 0,258 | 0 | 10 | 963-NRS4018T2R2MDGJ
 | 55 | 1 | 1 | L1 | ✓ | L1 | ✓ | Inductor | 10u 1A | 40x40 | 10 | 4 | Taiyo Yuden | NRS4018T100MDGJ |  | 963-NRS4018T100MDGJ | 0.258 | 10 | 587-2886-1-ND | 0.273 | 10 |  |  |  | Mouser | 20 | Mouser + | 5,16 |  |  |  | ✓ | 0,258 | 0,258 | 20 | 963-NRS4018T100MDGJ
Diodes |  |  |  |  |  |  |  |  |  |  |  |  |  |  |  |  |  |  |  |  |  |  |  |  |  |  |  |  |  |  |  |  | 0 | 0
 | 56 | 5 |  | D1, D2, D3, D4, D5 | ✓ |  | ✓ | Diode | 2A 30V Schottky | SOD123/ SOD123FL | 25 |  | ON Semi | MBR230LSFT1 | Comchip CDBMT240-HF | 863-MBR230LSFT1G | 0.096 | 100 | MBR230LSFT1GOSCT-ND | 0.207 | 25 |  |  |  | DK | 30 | DK + |  | 6,21 |  | Ersatzmodell bestellt | ✓ | 1,035 | 0 |  |  | 30 | MBR230LSFT1GOSCT-ND
LEDs |  |  |  |  |  |  |  |  |  |  |  |  |  |  |  |  |  |  |  |  |  |  |  |  |  |  |  |  |  |  |  |  | 0 | 0
 | 57 | 4 | 4 | LED1, LED2, LED3, LED4 | ✓ | LED1, LED2, LED3, LED4 | ✓ | LED | any color, 100mcd min | 0603_POL | 40 |  | Vishay | VLMY1300-GS08 (yellow) | Osram LS Q976-NR-1 | 78-VLMY1300-GS08 | 0.061 | 10 | 475-2512-1-ND | 0,072 | 10 |  |  |  | Mouser | 60 | Bestand | 3,66 |  |  |  | (✓) | 0,244 | 0,244 | 60 | 78-VLMY1300-GS08
ICs |  |  |  |  |  |  |  |  |  |  |  |  |  |  |  |  |  |  |  |  |  |  |  |  |  |  |  |  |  |  |  |  | 0 | 0
 | 58 | 1 |  | IC1 | ✓ |  | ✓ | IC | LAN8720A | QFN24-0.5 | 5 |  | SMSC/Microchip | LAN8720A/ LAN8720AI |  | 886-LAN8720A-CP | 0,944 | 1 | LAN8720A-CP-CT-ND | 0,96 | 1 |  |  |  | Mouser | 6 | Mouser + | 5,664 |  |  |  | ✓ | 0,944 | 0 | 6 | 886-LAN8720A-CP
 | 59 | 1 |  | IC2 | ✓ |  | ✓ | IC | TLV320AIC3100 | QFN32-0.5 | 5 |  | TI | TLV320AIC3100IRHBR/T |  | 595-V320AIC3100IRHBT | 4,54 | 1 | 296-25494-1-ND | 4,01 | 1 |  |  |  | DK | 6 | DK + |  | 24,06 |  |  | ✓ | 4,01 | 0 |  |  | 6 | 296-25494-1-ND
 | 60 | 1 |  | IC3 | ✓ |  | ✓ | IC | TPS2500 | SON10-0.5 | 5 |  | TI | TPS2500DRCT |  | 595-TPS2500DRCT | 2,82 | 1 | 296-32462-1-ND | 2,88 | 1 |  |  |  | Mouser | 6 | Mouser + | 16,92 |  |  |  | ✓ | 2,82 | 0 | 6 | 595-TPS2500DRCT
 | 61 | 5 | 2 | IC4, IC5, IC6, IC7, IC8 | ✓ | IC4, IC5 | ✓ | IC | AAT4280A | SC70JW-8 | 35 |  | Skyworks | AAT4280A |  | 873-AAT4280AIJS-2-T1 | 0,136 | 1 | 863-1480-1-ND | 0,21 | 1 |  |  |  | Mouser | 60 | Mouser + | 8,16 |  |  |  | ✓ | 0,68 | 0,272 | 60 | 873-AAT4280AIJS-2-T1
 | 62 | 1 |  | IC9 | ✓ |  |  | IC | FXMA108 | DFN20 | 5 |  | Fairchild | FXMA108 |  | 512-FXMA108BQX | 1.18 | 1 | FXMA108BQXFSCT-ND | 1,21 | 1 |  |  |  | Mouser | 6 | Mouser + | 7,08 |  |  |  | ✓ | 1,18 | 0 | 6 | 512-FXMA108BQX
 | 63 | 1 |  | MCU | ✓ |  |  | IC | NXP1837 | QFP144-0.5 | 5 |  | NXP | LPC1837JBD144E |  | 771-LPC1837JBD144E | 10,02 | 1 | LPC1837JBD144E-ND | 8,37 | 60 |  |  |  | Mouser | 4 | Mouser + | 40,08 |  |  |  | ✓ | 10,02 | 0 | 4 | 771-LPC1837JBD144E
 | 64 | 1 | 1 | MCU1 | ✓ | NFR51822 | ✓ | IC | NRF51822 | QFN48-0.4 | 10 | 23 (alt) | Nordic Semi | NRF51822QFAA |  | 949-NRF51822-QFAA-R7 | 3,30 | 10 |  |  |  |  |  |  | Rutronik | 15 |  |  |  |  | TODO: Bei Rutronik bestellen |  | 0 | 0
 | 65 |  | 1 |  |  | PN532 | ✓ | IC | PN532 | QFN40 | 5 |  | NXP | PN5321A3HN/C106;55 |  | 771-PN5321A3HNC106 | 8,27 | 1 | 568-8600-ND | 8,22 | 1 |  |  |  | DK | 3 | DK + |  | 24,66 |  |  | ✓ | 0 | 8,22 |  |  | 3 | 568-8600-ND
 | 66 | 1 | 1 | PWR1 | ✓ | PWR | ✓ | IC | LTC4080 | DFN10 | 10 | 4 | Linear | LTC4080 | LTC4081 |  |  |  | LTC4081EDD#PBF-ND | 3,2 | 1 |  |  |  | DK | 8 | DK + |  | 25,6 |  |  | ✓ | 3,2 | 3,2 |  |  | 8 | LTC4081EDD#PBF-ND
 | 67 |  | 1 |  | ✓ | TRF | ✓ | IC | TRF7970A | QFN32-0.5 | 5 |  | TI | TRF7970A |  | 595-TRF7970ARHBR | 5,58 | 1 | 296-29355-1-ND | 5,65 | 1 |  |  |  | Mouser | 3 | Mouser + | 16,74 |  |  | TODO: Samples bestellen | ✓ | 0 | 5,58 | 3 | 595-TRF7970ARHBR
Modules |  |  |  |  |  |  |  |  |  |  |  |  |  |  |  |  |  |  |  |  |  |  |  |  |  |  |  |  |  |  |  |  | 0 | 0
 | 68 | 1 |  | WIFI | ✓ |  | ✓ | Module | CC3000 |  | 5 |  | TI | CC3000MOD |  | 595-CC3000MOD | 17,57 | 1 | 296-35512-1-ND | 18,01 | 1 |  |  |  | Mouser | 2 | Mouser + | 35,14 |  |  |  | ✓ | 17,57 | 0 | 2 | 595-CC3000MOD
Clocks |  |  |  |  |  |  |  |  |  |  |  |  |  |  |  |  |  |  |  |  |  |  |  |  |  |  |  |  |  |  |  |  | 0 | 0
 | 69 | 2 | 1 | X1, X3 | ✓ | X3 | ✓ | Crystal | 32.768KHz 12.5pF | 1206 | 15 |  | Abracon | ABS07 | TXC 9HT10-32.768KAZF-T, Citizen CM315D32768DZFT | 717-9HT10-32.768KAZF | 0,619 | 10 | 300-8814-1-ND | 0,768 | 10 |  |  |  | Mouser | 20 | Mouser + | 12,38 |  |  |  | ✓ | 1,238 | 0,619 | 20 | 717-9HT10-32.768KAZF
 | 70 | 1 |  | X2 | ✓ |  | ✓ | Crystal | 12MHz 10pF 40ppm | 3.2 x 2.5 | 5 | yeah! | AVX | CX3225GB12000P0HPQCC | ABM8G-12.000MHZ-4Y-T3 | 581-CX3225GB12PHPQCC | 0,704 | 1 | 535-10901-1-ND | 0,519 | 10 |  |  |  | DK | 10 | Bestand |  | 5,19 |  |  | (✓) | 0,519 | 0
 | 71 | 1 | 1 | X5 | ✓ | Y2 | ✓ | Crystal | 16MHz 8pF 40ppm | 2.5 x 2.0 | 10 | yeah! | AVX | CX2520DB16000D0GEJCC |  | 581-CX2520DB16DGEJCC | 1,17 | 1 | 1253-1122-1-ND | 0,981 | 10 |  |  |  | DK | 10 | Bestand |  | 9,81 |  |  | (✓) | 0,981 | 0,981
 | 72 |  | 2 |  |  | X_NXP, XTRF | ✓ | Crystal | 27.12MHz 10pF 20ppm | 5 x 3.2 | 10 |  | TXC | 7B-27.120MEEQ-T |  |  |  |  | 887-1309-1-ND | 0,769 | 10 |  |  |  | DK | 20 | DK + |  | 15,38 |  | Tim: Checke bitte nochmal die Specs | ✓ | 0 | 1,538 |  |  | 20 | 887-1309-1-ND
 | 73 | 1 |  | X4 | ✓ |  | ✓ | Oscillator | 50MHz | 2.5 x 2.0 | 5 |  | SiLabs | 501AAA50M0000DAG | SITime SiT8103AI-13-33E-50.00000X | 788-8103I-333E50X | 1,44 | 1 | 336-2981-ND | 0,8 | 1 |  |  |  | DK | 10 | DK + |  | 8 |  |  | ✓ | 0,8 | 0 |  |  | 10 | 336-2981-ND
RF |  |  |  |  |  |  |  |  |  |  |  |  |  |  |  |  |  |  |  |  |  |  |  |  |  |  |  |  |  |  |  |  | 0 | 0
 | 74 | 2 | 1 | ANT1, ANT2 | ✓ | ANT2 | ✓ | Antenna | 2.4GHz | 1206 | 15 | yeah! | Abracon | AMCA31-2R450G-S1F |  | 815-CA312R450GS1FT | 0,208 | 10 | 535-12386-1-ND | 0,138 | 10 |  |  |  | DK | 20 | Bestand |  | 2,76 |  |  | (✓) | 0,276 | 0,138
 | 75 | 1 | 1 | BAL1 | ✓ | BAL | ✓ | Balun | for NRF51822 | WLCSP5 | 10 |  | ST | BALF-NRF01D3 | BAL-NRF01D3 (worse) | 511-BAL-NRF01D3 | 0.495 | 10 | 497-13637-1-ND | 0.585 | 10 |  |  |  | Mouser | 10 | Mouser + | 4,95 |  |  | Zus. Rutronik | ✓ | 0,495 | 0,495 | 10 | 511-BAL-NRF01D3
Mechanical |  |  |  |  |  |  |  |  |  |  |  |  |  |  |  |  |  |  |  |  |  |  |  |  |  |  |  |  |  |  |  |  | 0 | 0
 | 76 | 2 |  | !PGM, RESET | ✓ |  | ✓ | Button | CK-KMR2 |  | 10 | yeah! | CK | KMR2xx |  | 611-KMR211G-LFS | 0,431 | 1 | CKN10272CT-ND | 0,48 | 10 |  |  |  | Mouser | 20 | Bestand | 8,62 |  |  |  | (✓) | 0,862 | 0
 | 77 | 1 |  | 5VDC_IN | ✓ |  | ✓ | Connector | Barrel 5.5/2.1 2A |  | 5 |  | CUI | PJ 102AH |  |  |  |  | CP-102AH-ND | 0,94 | 1 |  |  |  | DK | 6 | DK + |  | 5,64 |  |  | ✓ | 0,94 | 0 |  |  | 6 | CP-102AH-ND
 | 78 | 1 | 1 | BATT | ✓ | BATT | ✓ | Connector | 2mm LiPo/Li-Ion |  | 10 |  | JST | PH-H |  |  |  |  | 455-1749-1-ND | 0,414 | 10 |  |  |  | DK | 15 | DK + |  | 6,21 |  |  | ✓ | 0,414 | 0,414 |  |  | 15 | 455-1749-1-ND
 | 79 | 1 |  | ETH | ✓ |  | ✓ | Connector | RJ45-Mag-LEDs |  | 5 |  | WIZnet | RB1-125BAG1A |  | 950-RB1-125BAG1A | 2,18 | 1 | 1278-1011-ND | 2,16 | 1 |  |  |  | DK | 10 | DK + |  | 21,6 |  |  | ✓ | 2,16 | 0 |  |  | 10 | 1278-1011-ND
 | 80 | 1 |  | HEADPHONE | ✓ |  | ✓ | Connector | 3.5mm stereo |  | 5 |  | CUI | SJ 3523 | Switchcraft 35RASMT2BHNTRX | 502-35RASMT2BHNTRX | 0,528 | 1 | CP-3523SJCT-ND | 1,06 | 1 |  |  |  | Mouser | 10 | Mouser + | 5,28 |  |  |  | ✓ | 0,528 | 0 | 10 | 502-35RASMT2BHNTRX
 | 81 | 1 |  | SD_CARD | ✓ |  | ✓ | Connector | SD card holder |  | 5 |  | Amphenol | 101_00313 |  | 523-101-00313-68-02 | 1,53 | 1 |  |  |  |  |  |  | Mouser | 10 | Mouser + | 15,3 |  |  |  | ✓ | 1,53 | 0 | 10 | 523-101-00313-68-02
 | 82 | 1 | 1 | USB1 | ✓ | USB | ✓ | Connector | Micro USB-B |  | 10 | yeah! | FCI | 10104110-0001LF |  | 649-10104110-0001LF | 0,431 | 10 |  |  |  |  |  |  | Mouser | 20 | Bestand | 8,62 |  |  |  | (✓) | 0,431 | 0,431
 | 83 | 1 |  | USB0 | ? |  | ✓ | Connector | Micro USB-AB |  | 5 | yeah! | FCI | 10104111-0001LF |  | 649-10104111-0001LF | 0,431 | 10 |  |  |  |  |  |  | Mouser | 10 | Bestand | 4,31 |  |  |  | (✓) | 0,431 | 0
 |  |  |  | ARM DEBUGs |  |  |  |  |  |  |  |  |  |  |  |  |  |  |  |  |  |  |  | SUM |  |  |  | 227,014 | 206,92 | 57,8 |  |  | 58,08181 | 23,55648
 |  |  |  |  |  |  |  |  |  |  |  |  |  |  |  |  |  |  |  |  |  |  |  |  |  | #DK | 36
 |  |  |  |  |  |  |  |  |  |  |  |  |  |  |  |  |  |  |  |  |  |  |  |  |  | #Mouser | 23
 |  |  |  |  |  |  |  |  |  |  |  |  |  |  |  |  |  |  |  |  |  |  |  |  |  | #Schukat | 5
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

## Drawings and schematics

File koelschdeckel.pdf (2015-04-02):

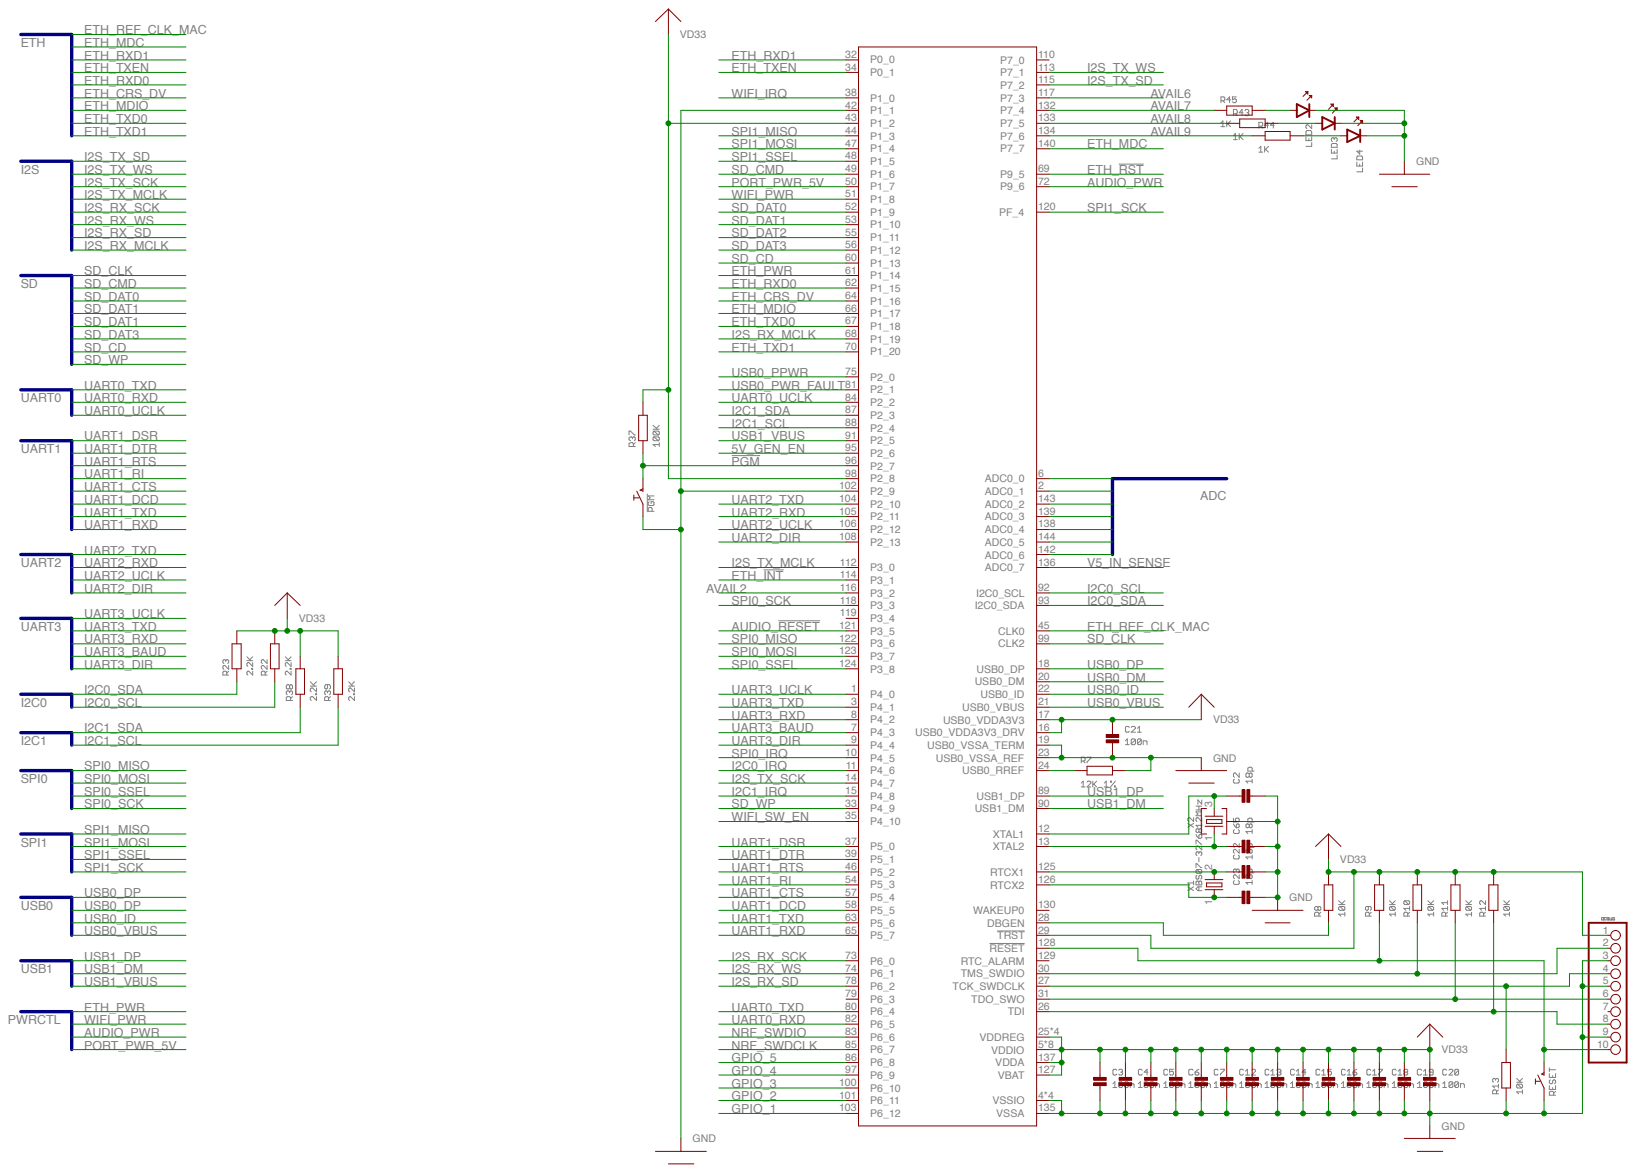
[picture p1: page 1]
XTAL1; XTAL2; RTCX1; RTCX2; ADC0_0; ADC0_1; ADC0_2; ADC0_3; USB0_DP; USB0_DM; USB0_ID; USB0_VDDA3V3; USB0_VDDA3V3_DRV; USB0_VSSA_TERM; USB0_VBUS; USB0_VSSA_REF; USB0_RREF; USB1_DP; USB1_DM; I2C0_SCL; I2C0_SDA; CLK0; CLK2; WAKEUP0; DBGEN; TRST; RESET; RTC_ALARM; TMS_SWDIO; TCK_SWDCLK; TDO_SWO; TDI; VDDREG; VDDIO; VDDA; VBAT; VSSIO; VSSA; ADC0_4; ADC0_5; ADC0_6; ADC0_7; GND; USB0; USB1; ADC; ETH; UART1; UART0; UART2; UART3; SPI0; SPI1; PWRCTL; USB0_DP USB0_DP; V5_IN_SENSE; ETH_RXD1; ETH_TXEN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

5V boost / USB OTG supply | 5V power distribution

# Plugs

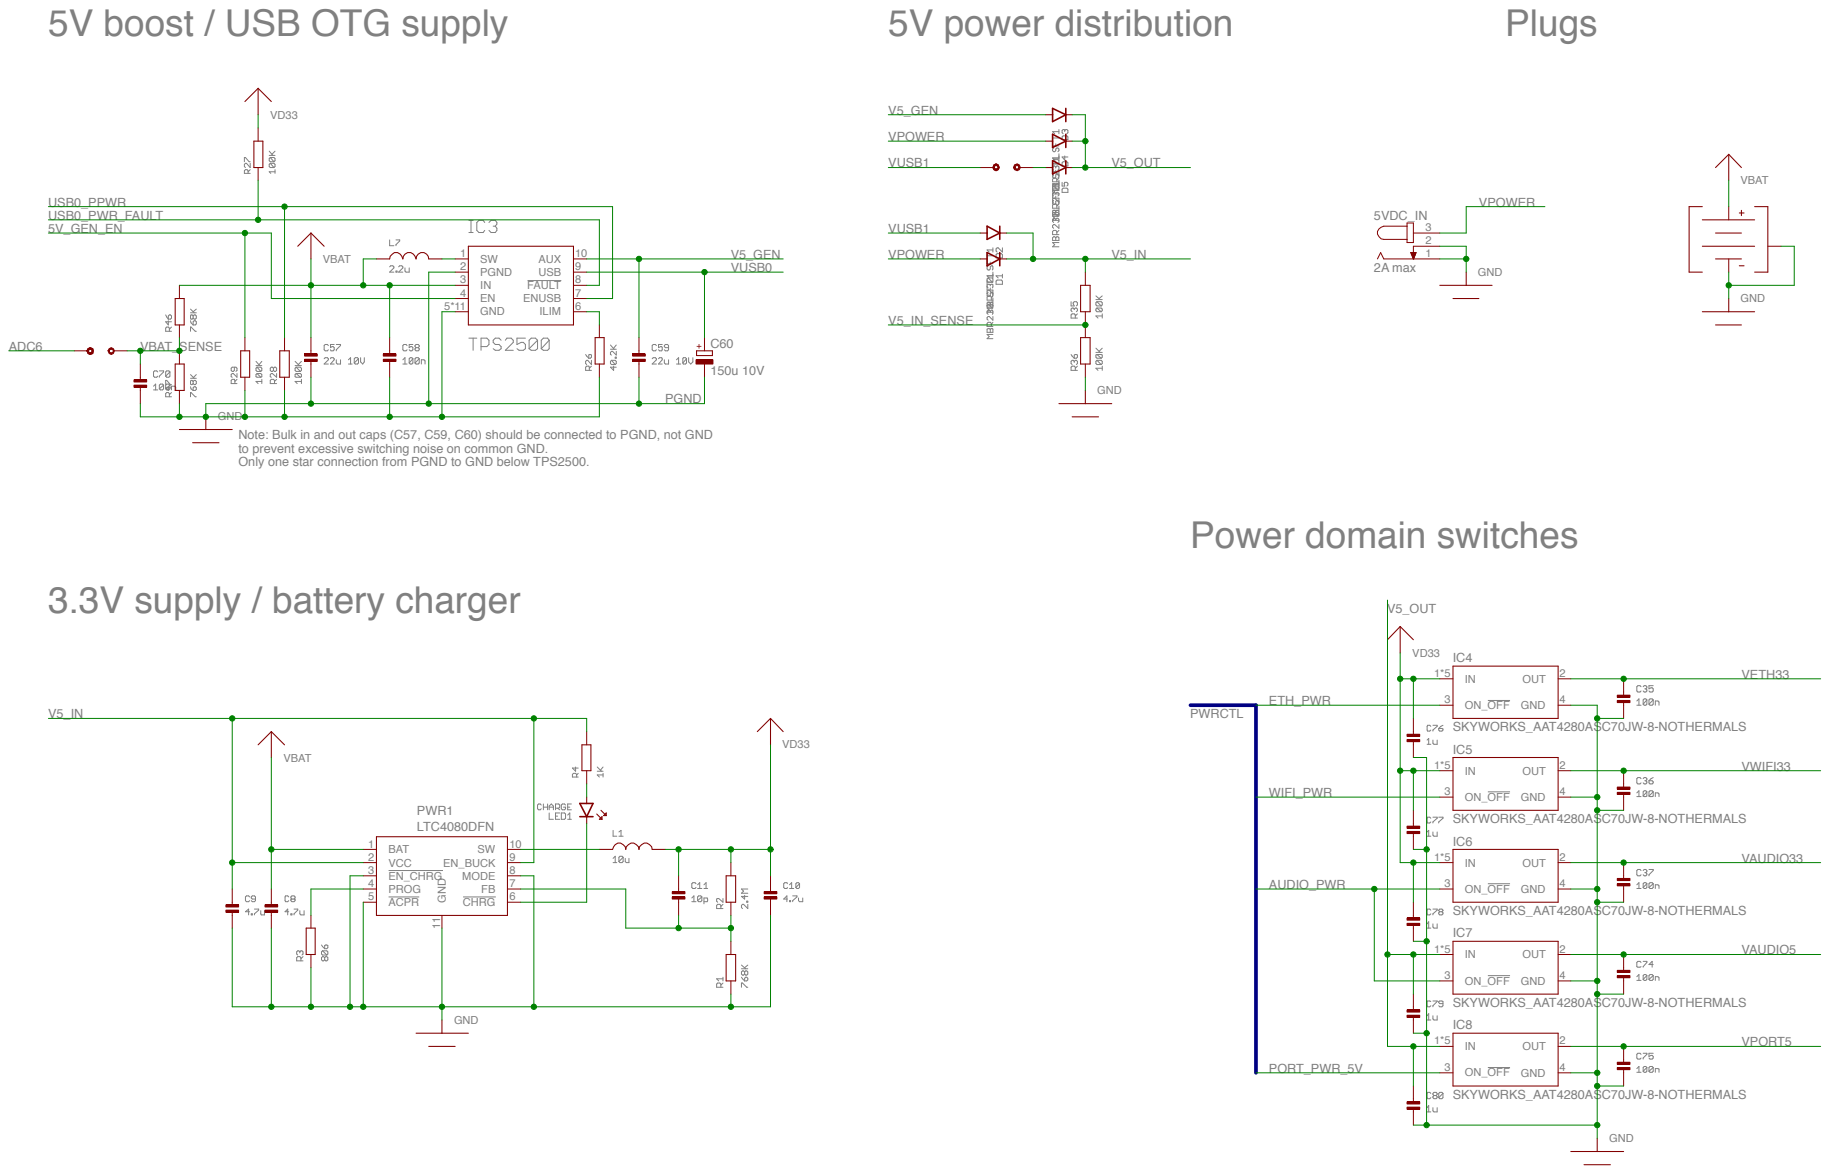
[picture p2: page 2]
PGND; LTC4080DFN; SKYWORKS_AAT4280ASC70JW-8-NOTHERMALS; 2A max; BAT 1 VCC 2 EN_CHRG 3 PROG 4 ACPR 5; EN_BUCK; MODE; CHRG; PWR1GND 11; GND; VBAT; SW 1 PGND 2 IN 3 EN 4 GND 5*11; AUX; USB; FAULT; ENUSB; ILIM; OUT; ON_OFF 3; 5VDC_IN3; PWRCTL; 5V_GEN_EN; USB0_PWR_FAULT; USB0_PPWR; VPOWER; V5_GEN; V5_OUT; VUSB1; VUSB0; V5_IN_SENSE; ETH_PWR; WIFI_PWR; AUDIO_PWR; VETH33; VWIFI33; VAUDIO33; VAUDIO5; VPORT5; PORT_PWR_5V; ADC6; VBAT_SENSE

GND
Note: Bulk in and out caps (C57, C59, C60) should be connected to PGND, not GND
to prevent excessive switching noise on common GND.
Only one star connection from PGND to GND below TPS2500.

Power domain switches

3.3V supply / battery charger

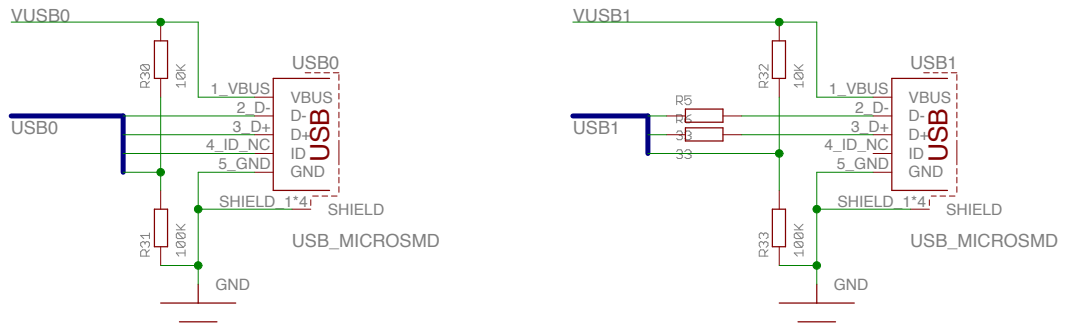
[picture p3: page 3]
USB_MICROSMD; USB0; VBUS 1_VBUS D- 2_D- D+ 3_D+; GND 5_GND; SHIELD SHIELD_1*4; GND; USB1; VUSB0; VUSB1 USB; USB

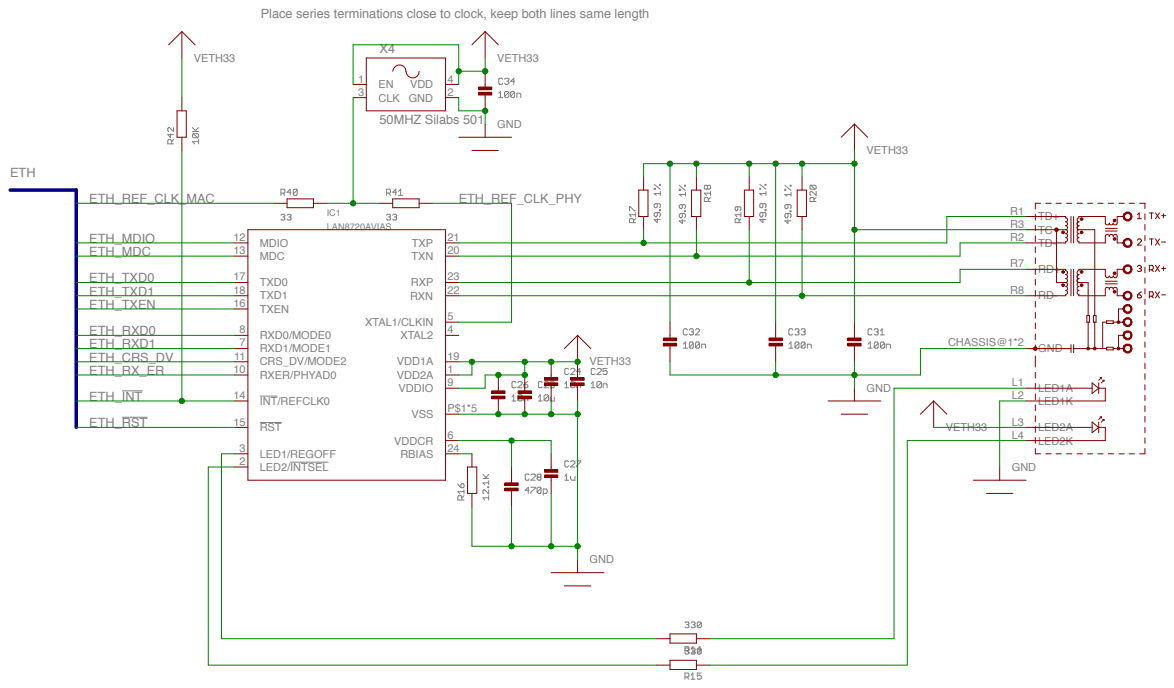
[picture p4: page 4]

Place series terminations close to clock, keep both lines same length

ETH_MDC

ETH_TXD1
ETH_TXEN

ETH_RXD0

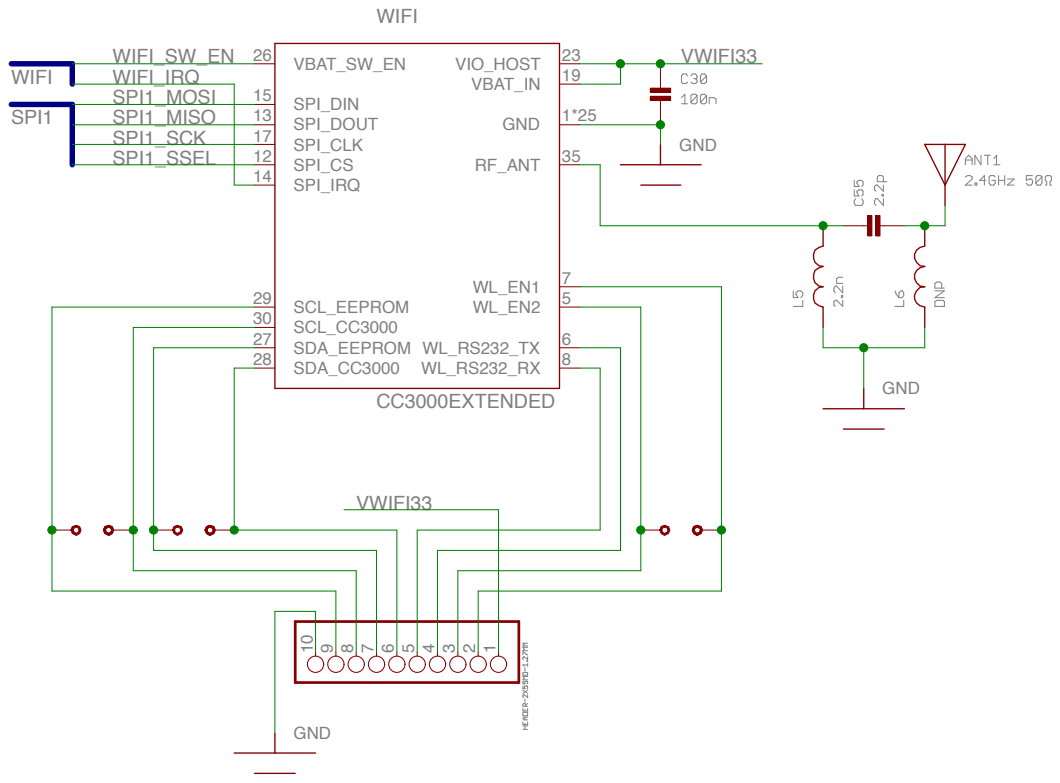
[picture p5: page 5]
CC3000EXTENDED; GND; SPI_DIN 15 SPI_DOUT 13 SPI_CLK 17 SPI_CS 12 SPI_IRQ 14; SCL_EEPROM 29; SDA_EEPROM 27; SCL_CC3000 30; SDA_CC3000 28; RF_ANT; VBAT_SW_EN 26; VIO_HOST; VBAT_IN; WIFI; SPI1; WIFI_SW_EN WIFI_IRQ; VWIFI33; SPI1_MOSI SPI1_MISO

SPI1_SCK
SPI1_SSEL

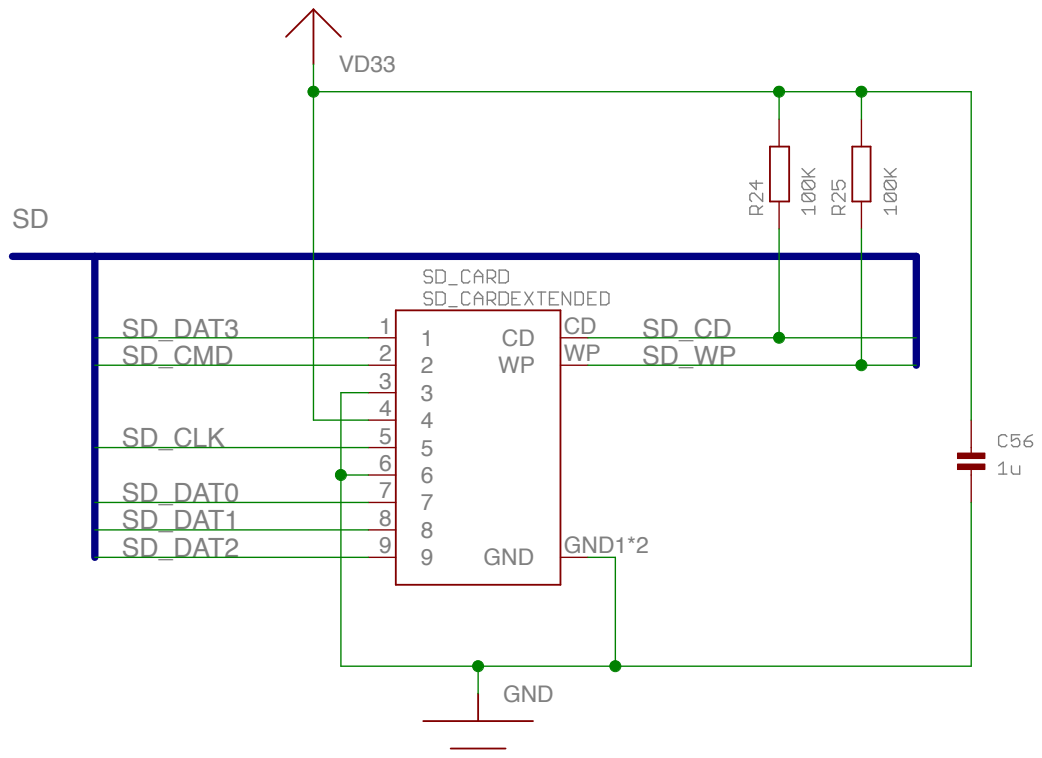
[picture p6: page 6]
GND; GND1*2; SD_DAT3 SD_CMD; SD_CLK

SD_DAT0
SD_DAT1
SD_DAT2

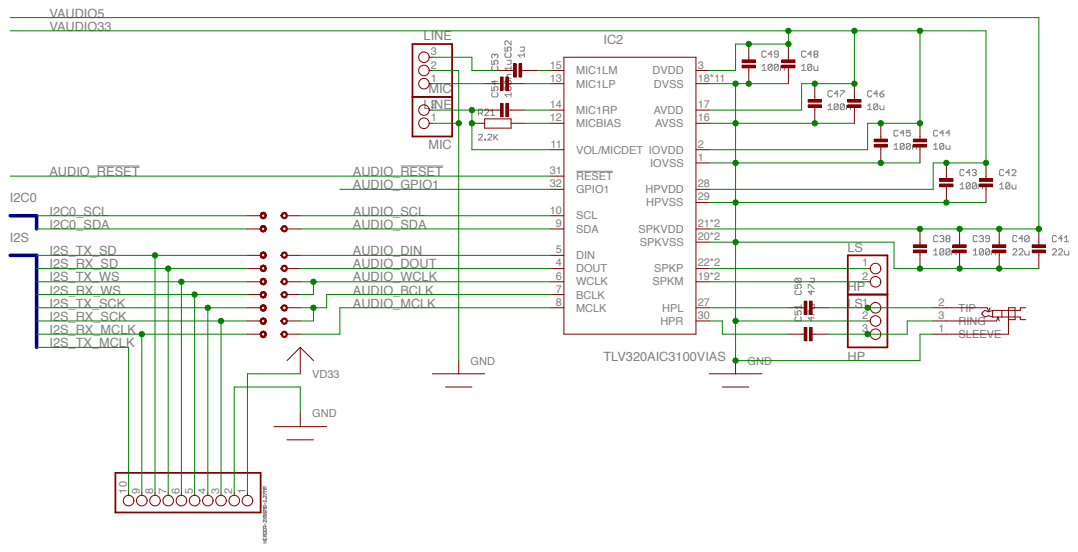
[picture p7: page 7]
TLV320AIC3100VIAS; MIC; LINE; DVDD; DVSS; AVDD; AVSS; IOVDD; IOVSS; HPVDD; HPVSS; SPKVDD; SPKVSS; SPKP; SPKM; HPL; HPR; MIC1LM 15; MIC1RP 14; MIC1LP 13; VOL/MICDET 11; RESET 31 GPIO1 32; SCL 10; SDA; DIN; DOUT; WCLK; BCLK; MCLK; MICBIAS 12; GND; MIC ¹; LINE 2123; TIP; RING; SLEEVE; AUDIO_RESET; AUDIO_GPIO1; AUDIO_SCL AUDIO_SDA; AUDIO_DOUT AUDIO_WCLK AUDIO_BCLK AUDIO_MCLK; I2S_TX_SD I2S_RX_SD I2S_TX_WS I2S_RX_WS I2S_TX_SCK I2S_RX_SCK I2S_RX_MCLK; I2C0_SCL I2C0_SDA; VAUDIO33; VAUDIO5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

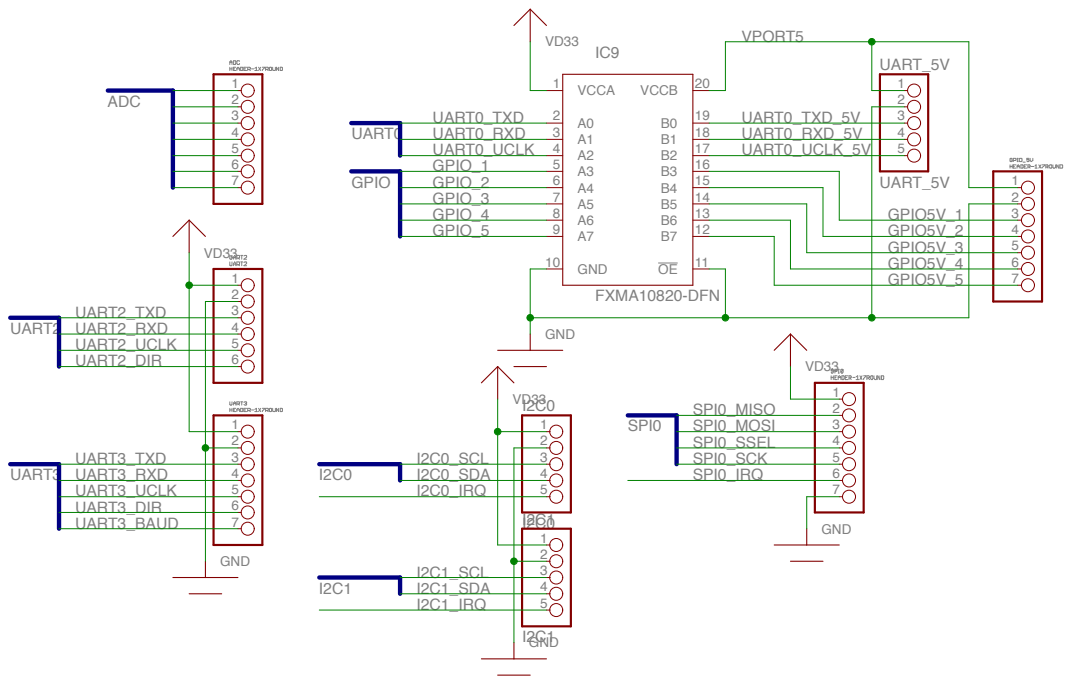
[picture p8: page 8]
FXMA10820-DFN; UART_5V; GND; GND 10; VCCA 1; VCCB; UART_5V 1 2 3 4 5; ADC; UART0; GPIO; SPI0; UART2; UART3; I2C0_SCL I2C0_SDA; I2C1_IRQ; I2C0_IRQ; VPORT5; UART0_TXD UART0_RXD UART0_UCLK; UART0_TXD_5V UART0_RXD_5V UART0_UCLK_5V; GPIO5V_1 GPIO5V_2 GPIO5V_3 GPIO5V_4 GPIO5V_5; GPIO_1 GPIO_2 GPIO_3 GPIO_4 GPIO_5; I2C1_SCL I2C1_SDA; SPI0_MISO SPI0_MOSI SPI0_SSEL SPI0_SCK SPI0_IRQ; UART2_TXD UART2_RXD UART2_UCLK UART2_DIR; UART3_TXD UART3_RXD UART3_UCLK UART3_DIR UART3_BAUD

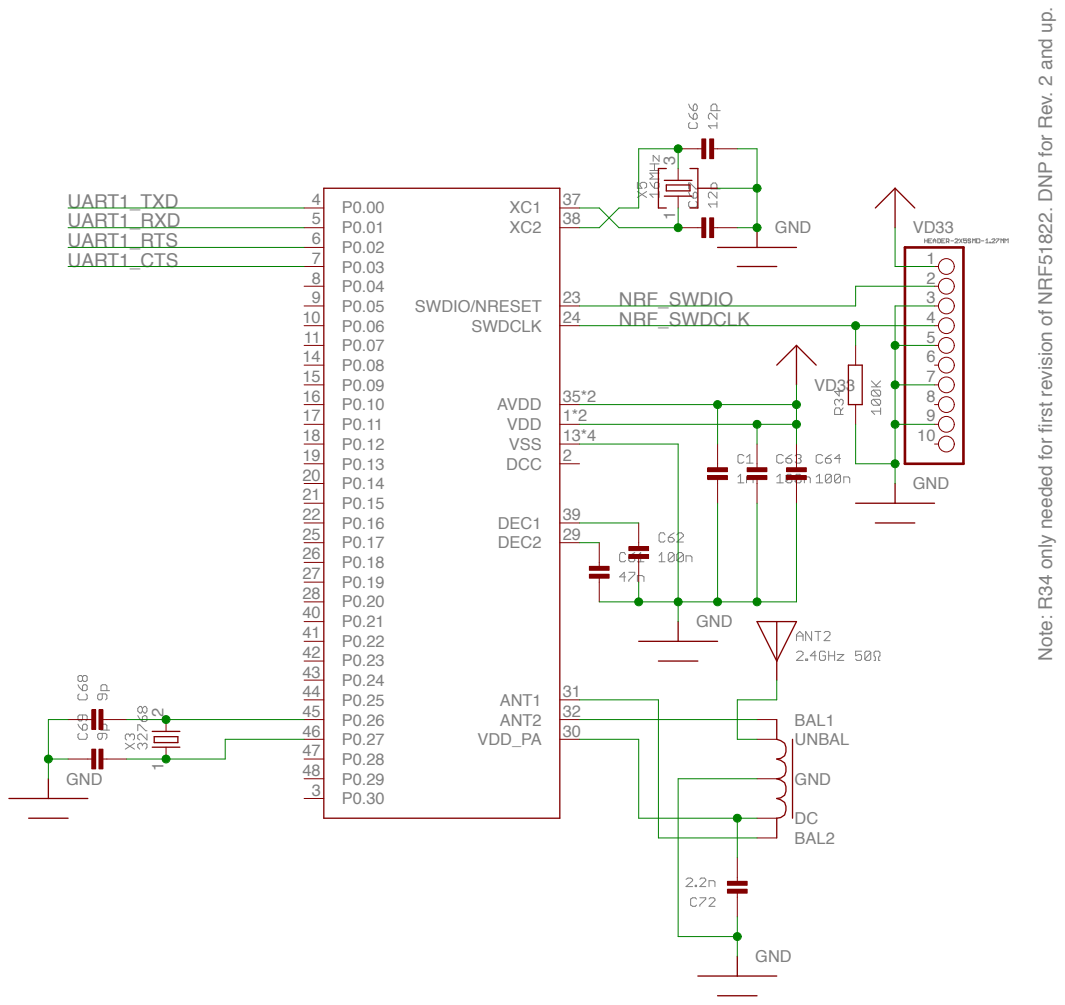
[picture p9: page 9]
SWDIO/NRESET; SWDCLK; VDD; VSS; DCC; AVDD; ANT1; ANT2; VDD_PA; DEC1; DEC2; GND; UNBAL; DC BAL2; BAL1; NRF_SWDIO NRF_SWDCLK; UART1_TXD UART1_RXD UART1_RTS UART1_CTS

Note: R34 only needed for first revision of NRF51822. DNP for Rev. 2 and up.

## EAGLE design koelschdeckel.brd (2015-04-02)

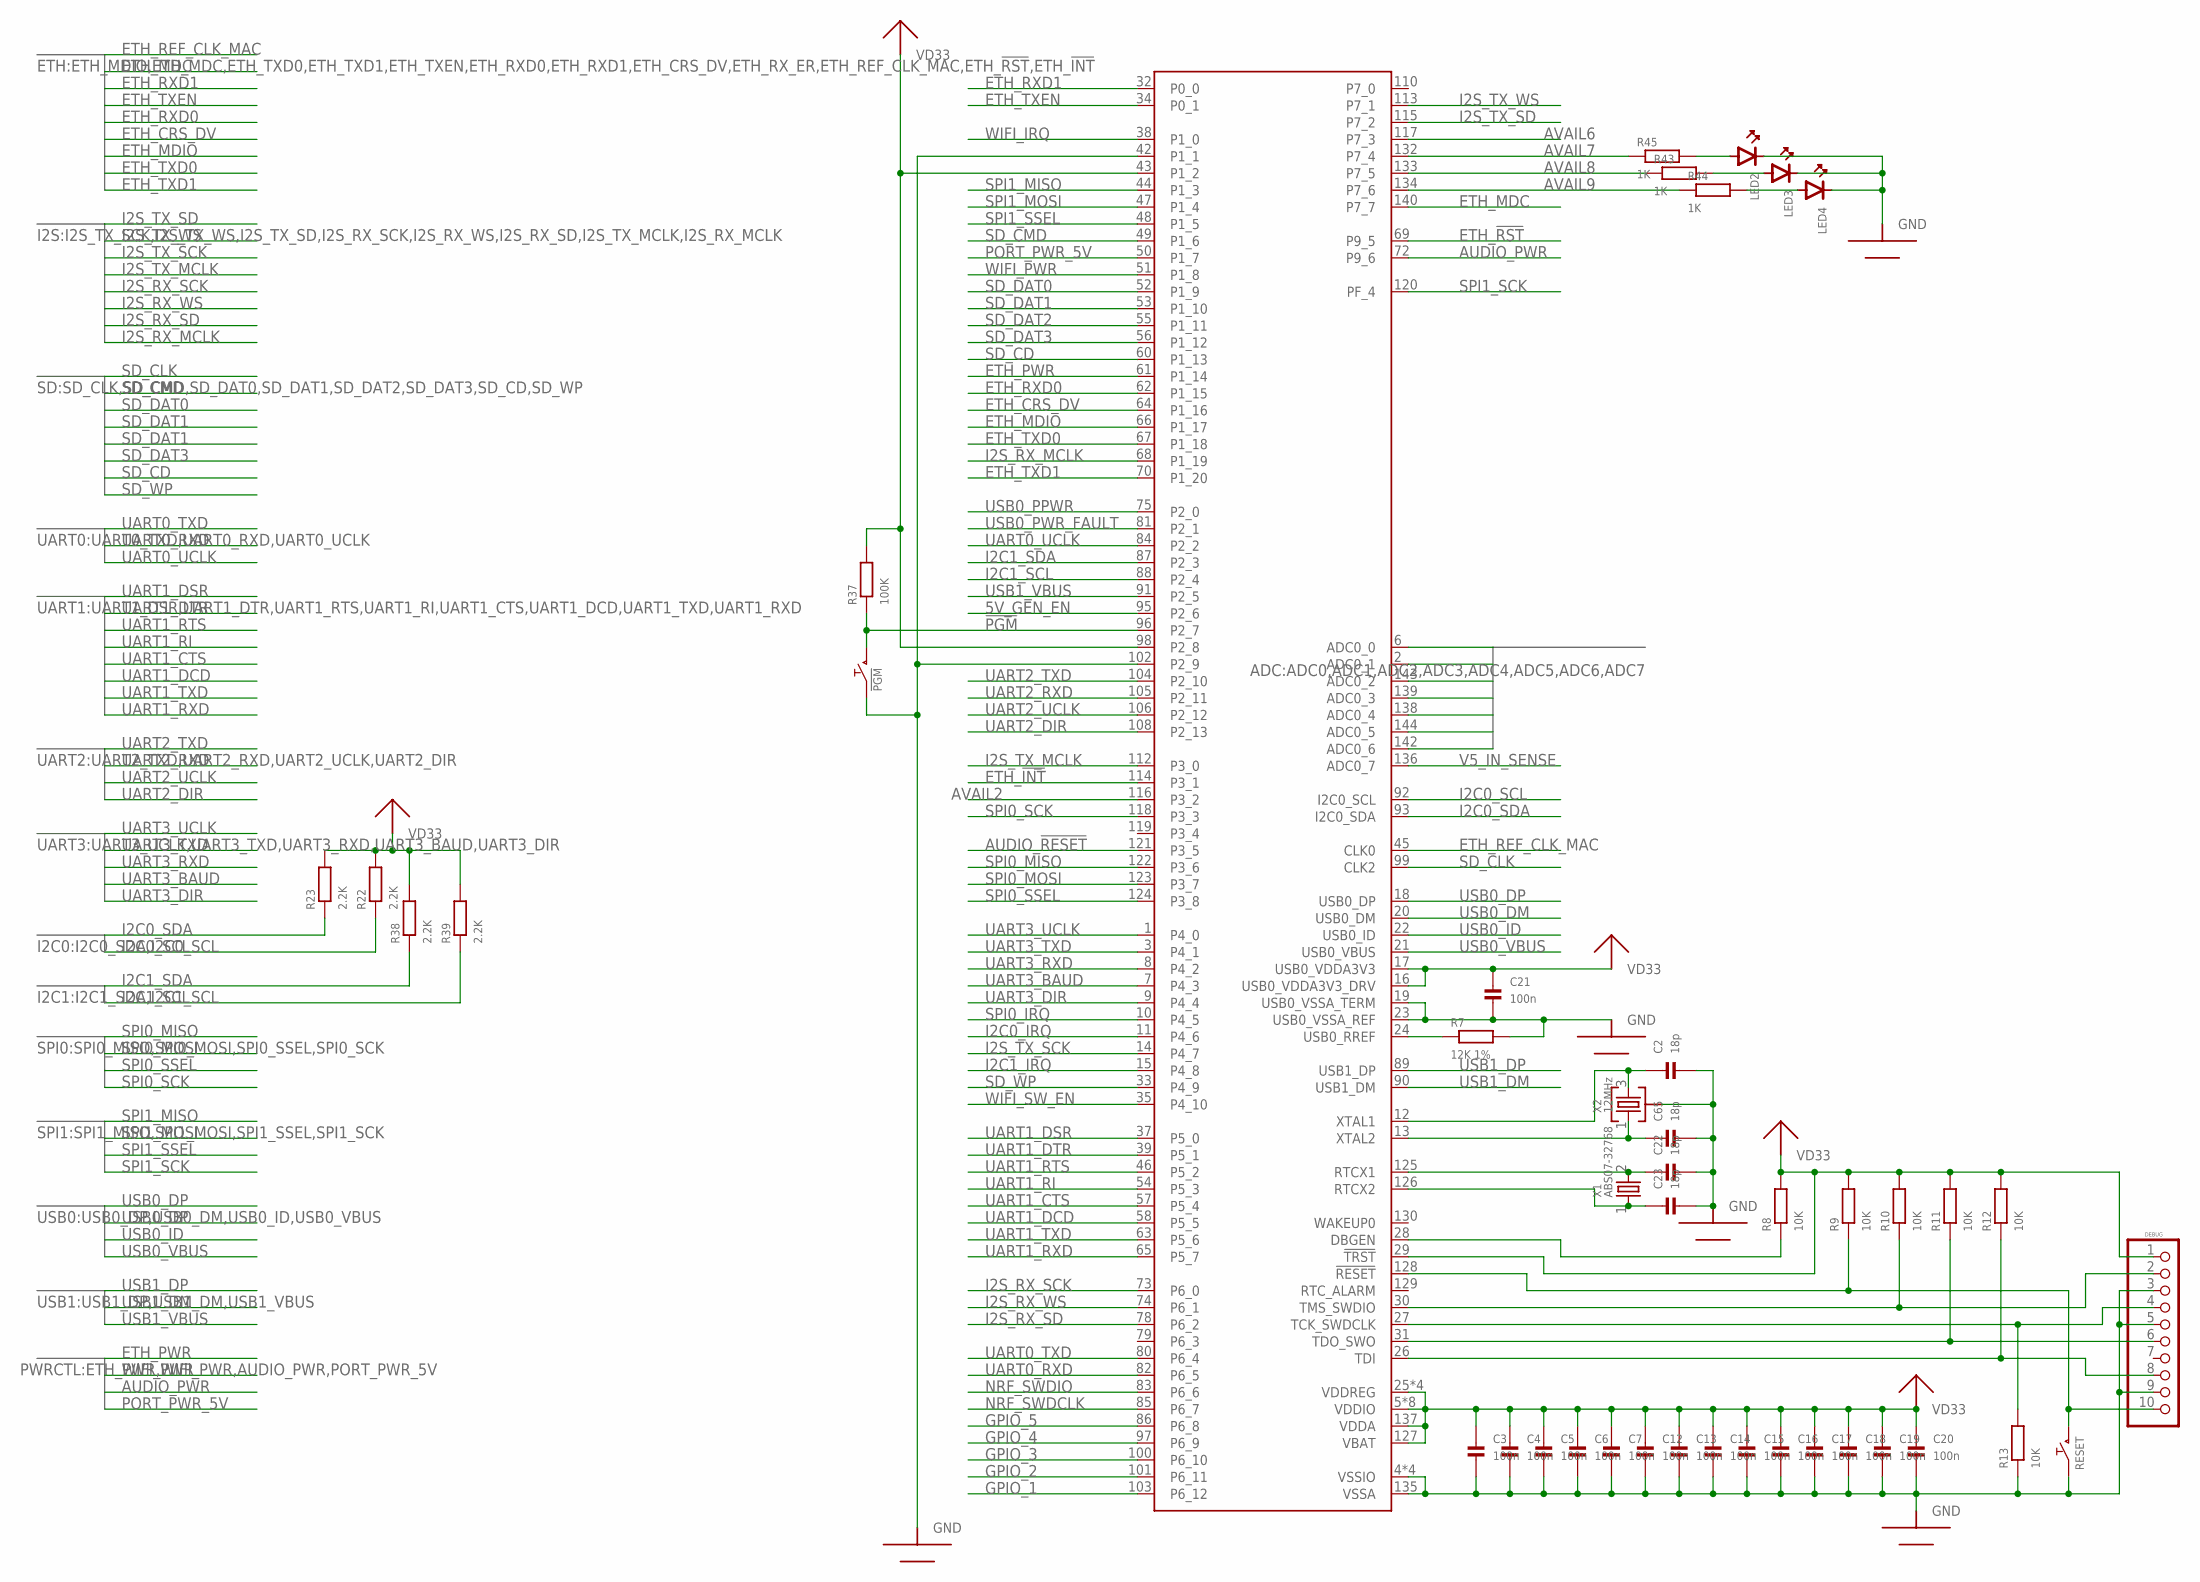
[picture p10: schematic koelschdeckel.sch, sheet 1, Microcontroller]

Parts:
!PGM: PUSHBUTTONKMR2XX; CK-KMR2
C2, C22, C23, C65: 18p; 0603
C3, C4, C5, C6, C7, C12, C13, C14, C15, C16, C17, C18, C19, C20, C21: 100n; 0603
LED2, LED3, LED4: LED0603; 0603_POLAR
LPC_DEBUG: DEBUG; 2X05_SMT
MCU: LPC1837; QFP144-0.5
R7: 12K 1%; 0603
R8, R9, R10, R11, R12, R13: 10K; 0603
R22, R23, R38, R39: 2.2K; 0603
R37: 100K; 0603
R43, R44, R45: 1K; 0603
RESET: PUSHBUTTONKMR2XX; CK-KMR2
X1: ABS07-32768; 1206_MINIMELF_COMBO
X2: 12MHz; ABM8G

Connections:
5V_GEN_EN: MCU.95 (P2_6); also elsewhere on the board
!PGM: !PGM.P$3 (2), !PGM.P$4 (2), MCU.96 (P2_7), R37.1
!RESET: LPC_DEBUG.10, MCU.128 (!RESET), R9.1, RESET.P$3 (2), RESET.P$4 (2)
ADC0: MCU.6 (ADC0_0); also elsewhere on the board
ADC1: MCU.2 (ADC0_1); also elsewhere on the board
ADC2: MCU.143 (ADC0_2); also elsewhere on the board
ADC3: MCU.139 (ADC0_3); also elsewhere on the board
ADC4: MCU.138 (ADC0_4); also elsewhere on the board
ADC5: MCU.144 (ADC0_5); also elsewhere on the board
ADC6: MCU.142 (ADC0_6); also elsewhere on the board
AUDIO_!RESET: MCU.121 (P3_5); also elsewhere on the board
AUDIO_PWR: MCU.72 (P9_6); also elsewhere on the board
AVAIL2: MCU.116 (P3_2)
AVAIL6: MCU.117 (P7_3)
AVAIL7: MCU.132 (P7_4), R45.1
AVAIL8: MCU.133 (P7_5), R43.1
AVAIL9: MCU.134 (P7_6), R44.1
DBGEN: MCU.28 (DBGEN), R8.1
ETH_!INT: MCU.114 (P3_1); also elsewhere on the board
ETH_!RST: MCU.69 (P9_5); also elsewhere on the board
ETH_CRS_DV: MCU.64 (P1_16); also elsewhere on the board
ETH_MDC: MCU.140 (P7_7); also elsewhere on the board
ETH_MDIO: MCU.66 (P1_17); also elsewhere on the board
ETH_PWR: MCU.61 (P1_14); also elsewhere on the board
ETH_REF_CLK_MAC: MCU.45 (CLK0); also elsewhere on the board
ETH_RXD0: MCU.62 (P1_15); also elsewhere on the board
ETH_RXD1: MCU.32 (P0_0); also elsewhere on the board
ETH_TXD0: MCU.67 (P1_18); also elsewhere on the board
ETH_TXD1: MCU.70 (P1_20); also elsewhere on the board
ETH_TXEN: MCU.34 (P0_1); also elsewhere on the board
GND: !PGM.P$1 (1), !PGM.P$2 (1), C2.2, C3.2, C4.2, C5.2, C6.2, C7.2, C12.2, C13.2, C14.2, C15.2, C16.2, C17.2, C18.2, C19.2, C20.2, C21.2, C22.2, C23.2, C65.2, LED2.K (CATHODE), LED3.K (CATHODE), LED4.K (CATHODE), LPC_DEBUG.3, LPC_DEBUG.5, LPC_DEBUG.9, MCU.4 (VSSIO), MCU.19 (USB0_VSSA_TERM), MCU.23 (USB0_VSSA_REF), MCU.40 (VSSIO), MCU.42 (P1_1), MCU.76 (VSSIO), MCU.102 (P2_9), MCU.109 (VSSIO), MCU.135 (VSSA), R7.2, R13.1, RESET.P$1 (1), RESET.P$2 (1), X2.2 (GND), X2.4 (GND); also elsewhere on the board
GPIO_1: MCU.103 (P6_12); also elsewhere on the board
GPIO_2: MCU.101 (P6_11); also elsewhere on the board
GPIO_3: MCU.100 (P6_10); also elsewhere on the board
GPIO_4: MCU.97 (P6_9); also elsewhere on the board
GPIO_5: MCU.86 (P6_8); also elsewhere on the board
I2C0_IRQ: MCU.11 (P4_6); also elsewhere on the board
I2C0_SCL: MCU.92 (I2C0_SCL), R22.1; also elsewhere on the board
I2C0_SDA: MCU.93 (I2C0_SDA), R23.1; also elsewhere on the board
I2C1_IRQ: MCU.15 (P4_8); also elsewhere on the board
I2C1_SCL: MCU.88 (P2_4), R39.1; also elsewhere on the board
I2C1_SDA: MCU.87 (P2_3), R38.1; also elsewhere on the board
I2S_RX_MCLK: MCU.68 (P1_19); also elsewhere on the board
I2S_RX_SCK: MCU.73 (P6_0); also elsewhere on the board
I2S_RX_SD: MCU.78 (P6_2); also elsewhere on the board
I2S_RX_WS: MCU.74 (P6_1); also elsewhere on the board
I2S_TX_MCLK: MCU.112 (P3_0); also elsewhere on the board
I2S_TX_SCK: MCU.14 (P4_7); also elsewhere on the board
I2S_TX_SD: MCU.115 (P7_2); also elsewhere on the board
I2S_TX_WS: MCU.113 (P7_1); also elsewhere on the board
unnamed: LED2.A (ANODE), R45.2
unnamed: LED3.A (ANODE), R43.2
unnamed: LED4.A (ANODE), R44.2
NRF_SWDCLK: MCU.85 (P6_7); also elsewhere on the board
NRF_SWDIO: MCU.83 (P6_6); also elsewhere on the board
PORT_PWR_5V: MCU.50 (P1_7); also elsewhere on the board
RTXC1: C22.1, MCU.125 (RTCX1), X1.2
RTXC2: C23.1, MCU.126 (RTCX2), X1.1
SD_CD: MCU.60 (P1_13); also elsewhere on the board
SD_CLK: MCU.99 (CLK2); also elsewhere on the board
SD_CMD: MCU.49 (P1_6); also elsewhere on the board
SD_DAT0: MCU.52 (P1_9); also elsewhere on the board
SD_DAT1: MCU.53 (P1_10); also elsewhere on the board
SD_DAT2: MCU.55 (P1_11); also elsewhere on the board
SD_DAT3: MCU.56 (P1_12); also elsewhere on the board
SD_WP: MCU.33 (P4_9); also elsewhere on the board
SPI0_IRQ: MCU.10 (P4_5); also elsewhere on the board
SPI0_MISO: MCU.122 (P3_6); also elsewhere on the board
SPI0_MOSI: MCU.123 (P3_7); also elsewhere on the board
SPI0_SCK: MCU.118 (P3_3); also elsewhere on the board
SPI0_SSEL: MCU.124 (P3_8); also elsewhere on the board
SPI1_MISO: MCU.44 (P1_3); also elsewhere on the board
SPI1_MOSI: MCU.47 (P1_4); also elsewhere on the board
SPI1_SCK: MCU.120 (PF_4); also elsewhere on the board
SPI1_SSEL: MCU.48 (P1_5); also elsewhere on the board
SWDCLK: LPC_DEBUG.4, MCU.27 (TCK_SWDCLK), R13.2
SWDIO: LPC_DEBUG.2, MCU.30 (TMS_SWDIO), R10.1
TDI: LPC_DEBUG.8, MCU.26 (TDI), R12.1
TDO_SWO: LPC_DEBUG.6, MCU.31 (TDO_SWO), R11.1
UART0_RXD: MCU.82 (P6_5); also elsewhere on the board
UART0_TXD: MCU.80 (P6_4); also elsewhere on the board
UART0_UCLK: MCU.84 (P2_2); also elsewhere on the board
UART1_CTS: MCU.57 (P5_4); also elsewhere on the board
UART1_DCD: MCU.58 (P5_5)
UART1_DSR: MCU.37 (P5_0)
UART1_DTR: MCU.39 (P5_1)
UART1_RI: MCU.54 (P5_3)
UART1_RTS: MCU.46 (P5_2); also elsewhere on the board
UART1_RXD: MCU.65 (P5_7); also elsewhere on the board
UART1_TXD: MCU.63 (P5_6); also elsewhere on the board
UART2_DIR: MCU.108 (P2_13); also elsewhere on the board
UART2_RXD: MCU.105 (P2_11); also elsewhere on the board
UART2_TXD: MCU.104 (P2_10); also elsewhere on the board
UART2_UCLK: MCU.106 (P2_12); also elsewhere on the board
UART3_BAUD: MCU.7 (P4_3); also elsewhere on the board
UART3_DIR: MCU.9 (P4_4); also elsewhere on the board
UART3_RXD: MCU.8 (P4_2); also elsewhere on the board
UART3_TXD: MCU.3 (P4_1); also elsewhere on the board
UART3_UCLK: MCU.1 (P4_0); also elsewhere on the board
USB0_DM: MCU.20 (USB0_DM); also elsewhere on the board
USB0_DP: MCU.18 (USB0_DP); also elsewhere on the board
USB0_ID: MCU.22 (USB0_ID); also elsewhere on the board
USB0_PPWR: MCU.75 (P2_0); also elsewhere on the board
USB0_PWR_FAULT: MCU.81 (P2_1); also elsewhere on the board
USB0_RREF: MCU.24 (USB0_RREF), R7.1
USB0_VBUS: MCU.21 (USB0_VBUS); also elsewhere on the board
USB1_DM: MCU.90 (USB1_DM); also elsewhere on the board
USB1_DP: MCU.89 (USB1_DP); also elsewhere on the board
USB1_VBUS: MCU.91 (P2_5); also elsewhere on the board
V5_IN_SENSE: MCU.136 (ADC0_7); also elsewhere on the board
VD33: C3.1, C4.1, C5.1, C6.1, C7.1, C12.1, C13.1, C14.1, C15.1, C16.1, C17.1, C18.1, C19.1, C20.1, C21.1, LPC_DEBUG.1, MCU.5 (VDDIO), MCU.16 (USB0_VDDA3V3_DRV), MCU.17 (USB0_VDDA3V3), MCU.25 (VDDREG), MCU.29 (!TRST), MCU.36 (VDDIO), MCU.41 (VDDIO), MCU.43 (P1_2), MCU.59 (VDDREG), MCU.71 (VDDIO), MCU.77 (VDDIO), MCU.94 (VDDREG), MCU.98 (P2_8), MCU.107 (VDDIO), MCU.111 (VDDIO), MCU.127 (VBAT), MCU.131 (VDDREG), MCU.137 (VDDA), MCU.141 (VDDIO), R8.2, R9.2, R10.2, R11.2, R12.2, R22.2, R23.2, R37.2, R38.2, R39.2; also elsewhere on the board
WIFI_IRQ: MCU.38 (P1_0); also elsewhere on the board
WIFI_PWR: MCU.51 (P1_8); also elsewhere on the board
WIFI_SW_EN: MCU.35 (P4_10); also elsewhere on the board
XTAL1: C2.1, MCU.12 (XTAL1), X2.3 (2)
XTAL2: C65.1, MCU.13 (XTAL2), X2.1

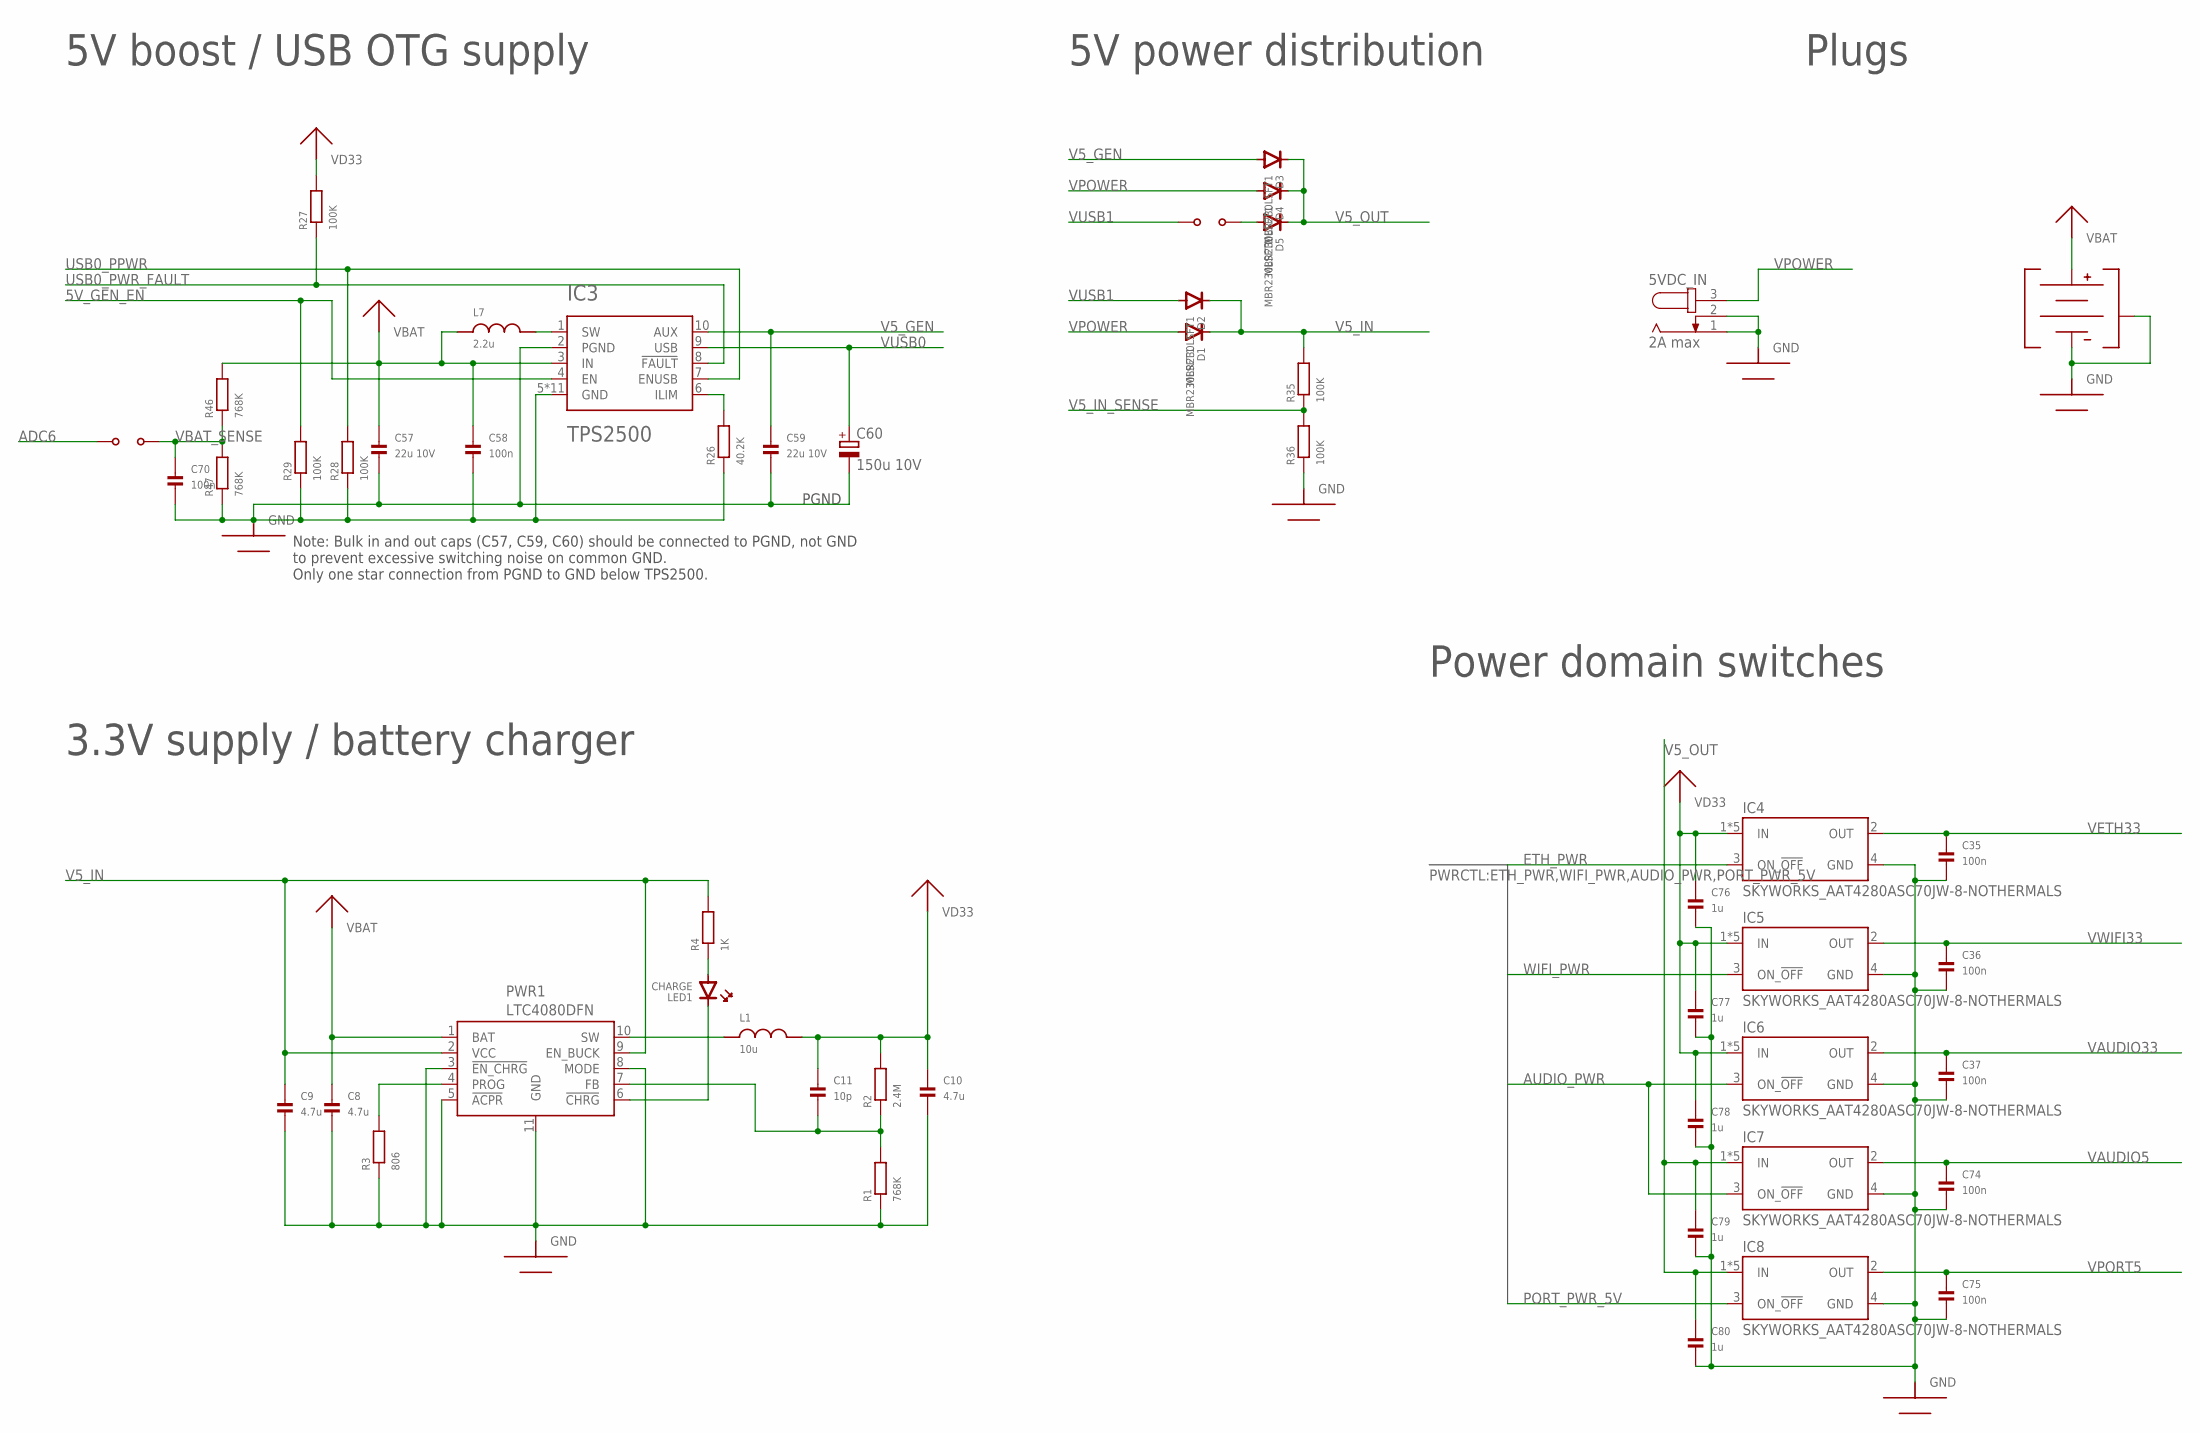
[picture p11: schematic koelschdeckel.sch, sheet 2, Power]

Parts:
5VDC_IN: 2A max; CUI_PJ_102BH
BATSNS: JUMPERSOLDER_CLOSED; 0603_SOLDERJUMPER_CLOSED
BATT: BATTERY_WITH_HOLDER; S2B-PH-SM4-TB
C8, C9, C10: 4.7u; 0603
C11: 10p; 0603
C35, C36, C37, C58, C70, C74, C75: 100n; 0603
C57, C59: 22u 10V; 0805
C60: 150u 10V; 1210_POLAR
C76, C77, C78, C79, C80: 1u; 0603
D1, D2, D3, D4, D5: MBR230LSFT1; SOD123FL
IC3: TPS2500; SON10-0.5-EP-VIAS
IC4, IC5, IC6, IC7, IC8: SKYWORKS_AAT4280ASC70JW-8-NOTHERMALS; SC70JW-8-NOTHERMALS
L1: 10u; INDUCTOR_40X40
L7: 2.2u; INDUCTOR_40X40
LED1: CHARGE; 0603_POLAR
LIM: JUMPERSOLDER_OPEN; 0603_SOLDERJUMPER_OPEN
PWR1: LTC4080DFN; LTC4080_DFN
R1, R46, R47: 768K; 0603
R2: 2.4M; 0603
R3: 806; 0603
R4: 1K; 0603
R26: 40.2K; 0603
R27, R28, R29, R35, R36: 100K; 0603

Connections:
5V_BOOST_SW: IC3.1 (SW), L7.P$2 (2)
5V_GEN_EN: IC3.4 (EN), R29.2; also elsewhere on the board
5V_ILIM: IC3.6 (ILIM), R26.2
ADC6: BATSNS.1; also elsewhere on the board
AUDIO_PWR: IC6.3 (ON_!OFF), IC7.3 (ON_!OFF); also elsewhere on the board
CHARGE_!CHRG: LED1.K (CATHODE), PWR1.6 (!CHRG)
CHARGE_!CHRG_CURR: LED1.A (ANODE), R4.1
CHARGE_FB: C11.2, PWR1.7 (FB), R1.2, R2.1
CHARGE_PROG: PWR1.4 (PROG), R3.2
CHARGE_SW: L1.P$1 (1), PWR1.10 (SW)
ETH_PWR: IC4.3 (ON_!OFF); also elsewhere on the board
GND: 5VDC_IN.1, 5VDC_IN.2, BATT.2 (-), BATT.3 (HOLDER), BATT.4 (HOLDER), C8.2, C9.2, C10.2, C35.2, C36.2, C37.2, C57.2, C58.2, C59.2, C60.K (-), C70.2, C74.2, C75.2, C76.2, C77.2, C78.2, C79.2, C80.2, IC3.2 (PGND), IC3.5 (GND), IC3.EXT1 (GND), IC3.EXT2 (GND), IC3.EXT3 (GND), IC3.EXT4 (GND), IC3.PAD (GND), IC3.THERM1 (GND), IC3.THERM2 (GND), IC3.THERM3 (GND), IC3.THERM4 (GND), IC3.THERM5 (GND), IC4.4 (GND), IC5.4 (GND), IC6.4 (GND), IC7.4 (GND), IC8.4 (GND), PWR1.3 (!EN_CHRG), PWR1.5 (!ACPR), PWR1.8 (MODE), PWR1.11 (GND), R1.1, R3.1, R26.1, R28.1, R29.1, R36.1, R47.1; also elsewhere on the board
PORT_PWR_5V: IC8.3 (ON_!OFF); also elsewhere on the board
USB0_PPWR: IC3.7 (ENUSB), R28.2; also elsewhere on the board
USB0_PWR_FAULT: IC3.8 (!FAULT), R27.1; also elsewhere on the board
V5_GEN: C59.1, D3.A (ANODE), IC3.10 (AUX)
V5_IN: C9.1, D1.K (CATHODE), D2.K (CATHODE), PWR1.2 (VCC), PWR1.9 (EN_BUCK), R4.2, R35.2
V5_IN_SENSE: R35.1, R36.2; also elsewhere on the board
V5_OUT: C79.1, C80.1, D3.K (CATHODE), D4.K (CATHODE), D5.K (CATHODE), IC7.1 (IN), IC7.5 (IN), IC7.6 (IN), IC7.7 (IN), IC7.8 (IN), IC8.1 (IN), IC8.5 (IN), IC8.6 (IN), IC8.7 (IN), IC8.8 (IN)
VAUDIO5: C74.1, IC7.2 (OUT); also elsewhere on the board
VAUDIO33: C37.1, IC6.2 (OUT); also elsewhere on the board
VBAT: BATT.1 (+), C8.1, C57.1, C58.1, IC3.3 (IN), L7.P$1 (1), PWR1.1 (BAT), R46.2
VBAT_SENSE: BATSNS.2, C70.1, R46.1, R47.2
VD33: C10.1, C11.1, C76.1, C77.1, C78.1, IC4.1 (IN), IC4.5 (IN), IC4.6 (IN), IC4.7 (IN), IC4.8 (IN), IC5.1 (IN), IC5.5 (IN), IC5.6 (IN), IC5.7 (IN), IC5.8 (IN), IC6.1 (IN), IC6.5 (IN), IC6.6 (IN), IC6.7 (IN), IC6.8 (IN), L1.P$2 (2), R2.2, R27.2; also elsewhere on the board
VETH33: C35.1, IC4.2 (OUT); also elsewhere on the board
VPORT5: C75.1, IC8.2 (OUT); also elsewhere on the board
VPOWER: 5VDC_IN.3, D1.A (ANODE), D4.A (ANODE)
VUSB0: C60.A (+), IC3.9 (USB); also elsewhere on the board
VUSB1: D2.A (ANODE), LIM.1; also elsewhere on the board
VUSB1_V5_OUT: D5.A (ANODE), LIM.2
VWIFI33: C36.1, IC5.2 (OUT); also elsewhere on the board
WIFI_PWR: IC5.3 (ON_!OFF); also elsewhere on the board

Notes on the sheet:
5V power distribution
5V boost / USB OTG supply
3.3V supply / battery charger
Power domain switches
Plugs
Note: Bulk in and out caps (C57, C59, C60) should be connected to PGND, not GND to prevent excessive switching noise on common GND. Only one star connection from PGND to GND below TPS2500.
PGND

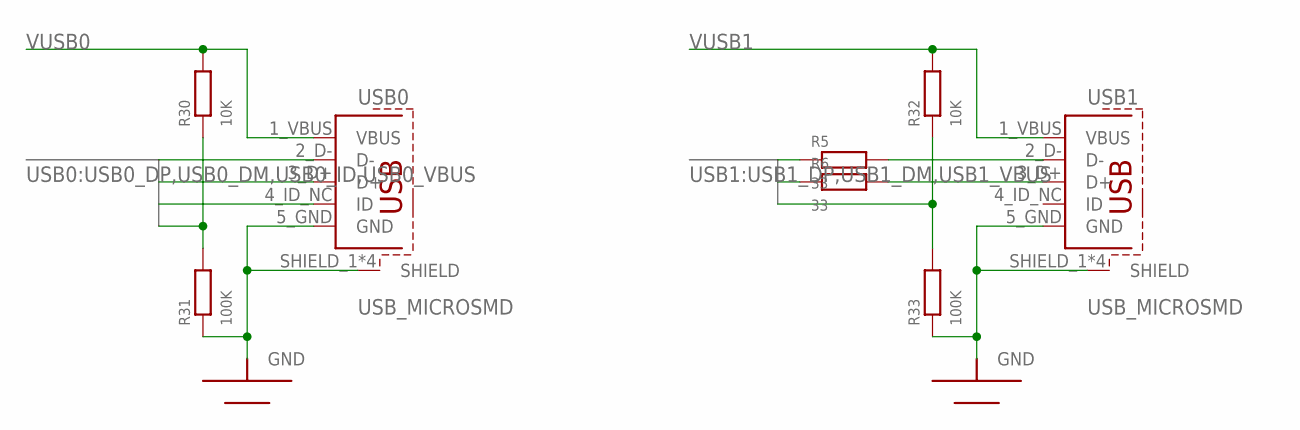
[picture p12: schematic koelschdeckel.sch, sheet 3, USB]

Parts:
R5, R6: 33; 0603
R30, R32: 10K; 0603
R31, R33: 100K; 0603
USB0, USB1: USB_MICROSMD; USB_MICRO_SMD

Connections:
GND: R31.1, R33.1, USB0.5_GND (GND), USB0.SHIELD_1 (SHIELD), USB0.SHIELD_2 (SHIELD), USB0.SHIELD_3 (SHIELD), USB0.SHIELD_4 (SHIELD), USB1.5_GND (GND), USB1.SHIELD_1 (SHIELD), USB1.SHIELD_2 (SHIELD), USB1.SHIELD_3 (SHIELD), USB1.SHIELD_4 (SHIELD); also elsewhere on the board
USB0_DM: USB0.2_D- (D-); also elsewhere on the board
USB0_DP: USB0.3_D+ (D+); also elsewhere on the board
USB0_ID: USB0.4_ID_NC (ID); also elsewhere on the board
USB0_VBUS: R30.1, R31.2; also elsewhere on the board
USB1_DM: R5.1; also elsewhere on the board
USB1_DM_LINE: R5.2, USB1.2_D- (D-)
USB1_DP: R6.1; also elsewhere on the board
USB1_VBUS: R32.1, R33.2; also elsewhere on the board
USB_DP_LINE: R6.2, USB1.3_D+ (D+)
VUSB0: R30.2, USB0.1_VBUS (VBUS); also elsewhere on the board
VUSB1: R32.2, USB1.1_VBUS (VBUS); also elsewhere on the board

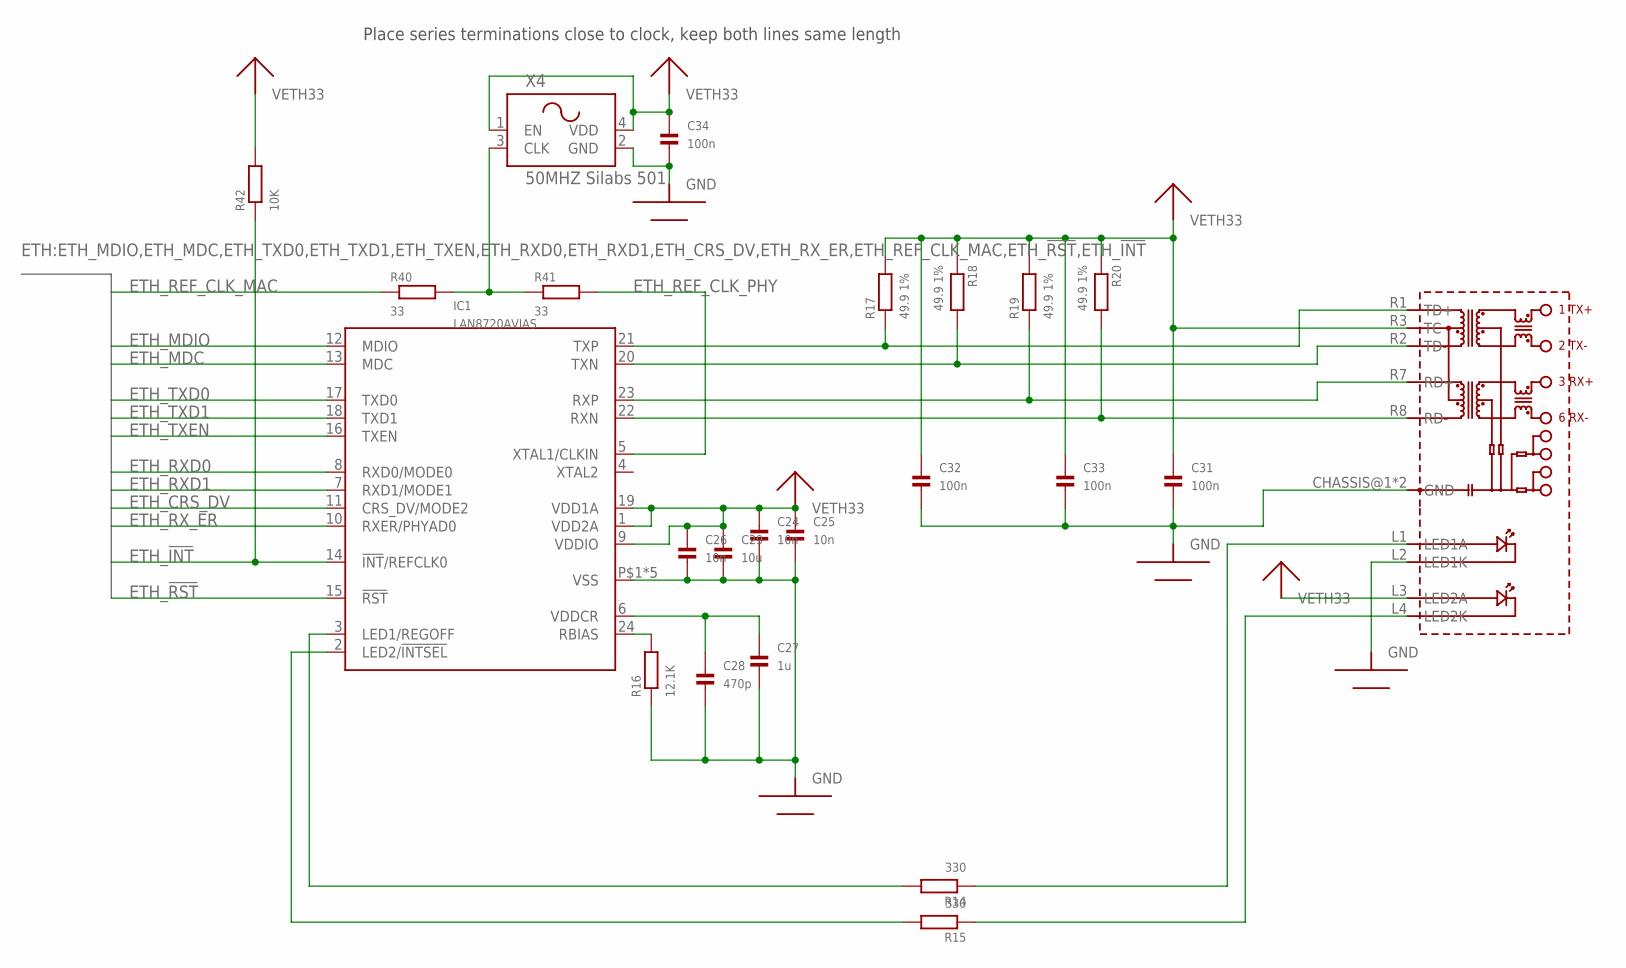
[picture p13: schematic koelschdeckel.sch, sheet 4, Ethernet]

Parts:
C24, C25, C26: 10n; 0603
C27: 1u; 0603
C28: 470p; 0603
C29: 10u; 0603
C31, C32, C33, C34: 100n; 0603
ETH: ETHERNET_JACK_LEDSRB1-125BAG1A; RJ45-RB1-125BAG1A
IC1: LAN8720AVIAS; QFN24-0.5-EP-VIAS
R14, R15: 330; 0603
R16: 12.1K; 0603
R17, R18, R19, R20: 49.9 1%; 0603
R40, R41: 33; 0603
R42: 10K; 0603
X4: 50MHZ Silabs 501; CRYSTAL25X20

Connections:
ETH_!INT: IC1.14 (!INT!/REFCLK0), R42.1; also elsewhere on the board
ETH_!RST: IC1.15 (!RST); also elsewhere on the board
ETH_CRS_DV: IC1.11 (CRS_DV/MODE2); also elsewhere on the board
ETH_LED1: IC1.3 (LED1/REGOFF), R14.2
ETH_LED1_CURR: ETH.L1 (LED1A), R14.1
ETH_LED2: IC1.2 (LED2/!INTSEL), R15.2
ETH_LED2_CURR: ETH.L4 (LED2K), R15.1
ETH_MDC: IC1.13 (MDC); also elsewhere on the board
ETH_MDIO: IC1.12 (MDIO); also elsewhere on the board
ETH_RBIAS: IC1.24 (RBIAS), R16.2
ETH_REF_CLK: R40.2, R41.1, X4.3 (CLK)
ETH_REF_CLK_MAC: R40.1; also elsewhere on the board
ETH_REF_CLK_PHY: IC1.5 (XTAL1/CLKIN), R41.2
ETH_RXD0: IC1.8 (RXD0/MODE0); also elsewhere on the board
ETH_RXD1: IC1.7 (RXD1/MODE1); also elsewhere on the board
ETH_RXN: ETH.R8 (RD-), IC1.22 (RXN), R20.2
ETH_RXP: ETH.R7 (RD+), IC1.23 (RXP), R19.1
ETH_RX_ER: IC1.10 (RXER/PHYAD0)
ETH_TXD0: IC1.17 (TXD0); also elsewhere on the board
ETH_TXD1: IC1.18 (TXD1); also elsewhere on the board
ETH_TXEN: IC1.16 (TXEN); also elsewhere on the board
ETH_TXN: ETH.R2 (TD-), IC1.20 (TXN), R18.2
ETH_TXP: ETH.R1 (TD+), IC1.21 (TXP), R17.1
ETH_VDDCR: C27.1, C28.1, IC1.6 (VDDCR)
GND: C24.2, C25.2, C26.2, C27.2, C28.2, C29.2, C31.2, C32.2, C33.2, C34.2, ETH.CHASSIS@1 (GND), ETH.CHASSIS@2 (GND), ETH.L2 (LED1K), IC1.P$1 (VSS), IC1.P$2 (VSS), IC1.P$3 (VSS), IC1.P$4 (VSS), IC1.PAD (VSS), R16.1, X4.2 (GND); also elsewhere on the board
VETH33: C24.1, C25.1, C26.1, C29.1, C31.1, C32.1, C33.1, C34.1, ETH.L3 (LED2A), ETH.R3 (TC), IC1.1 (VDD2A), IC1.9 (VDDIO), IC1.19 (VDD1A), R17.2, R18.1, R19.2, R20.1, R42.2, X4.1 (EN), X4.4 (VDD); also elsewhere on the board

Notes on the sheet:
Place series terminations close to clock, keep both lines same length

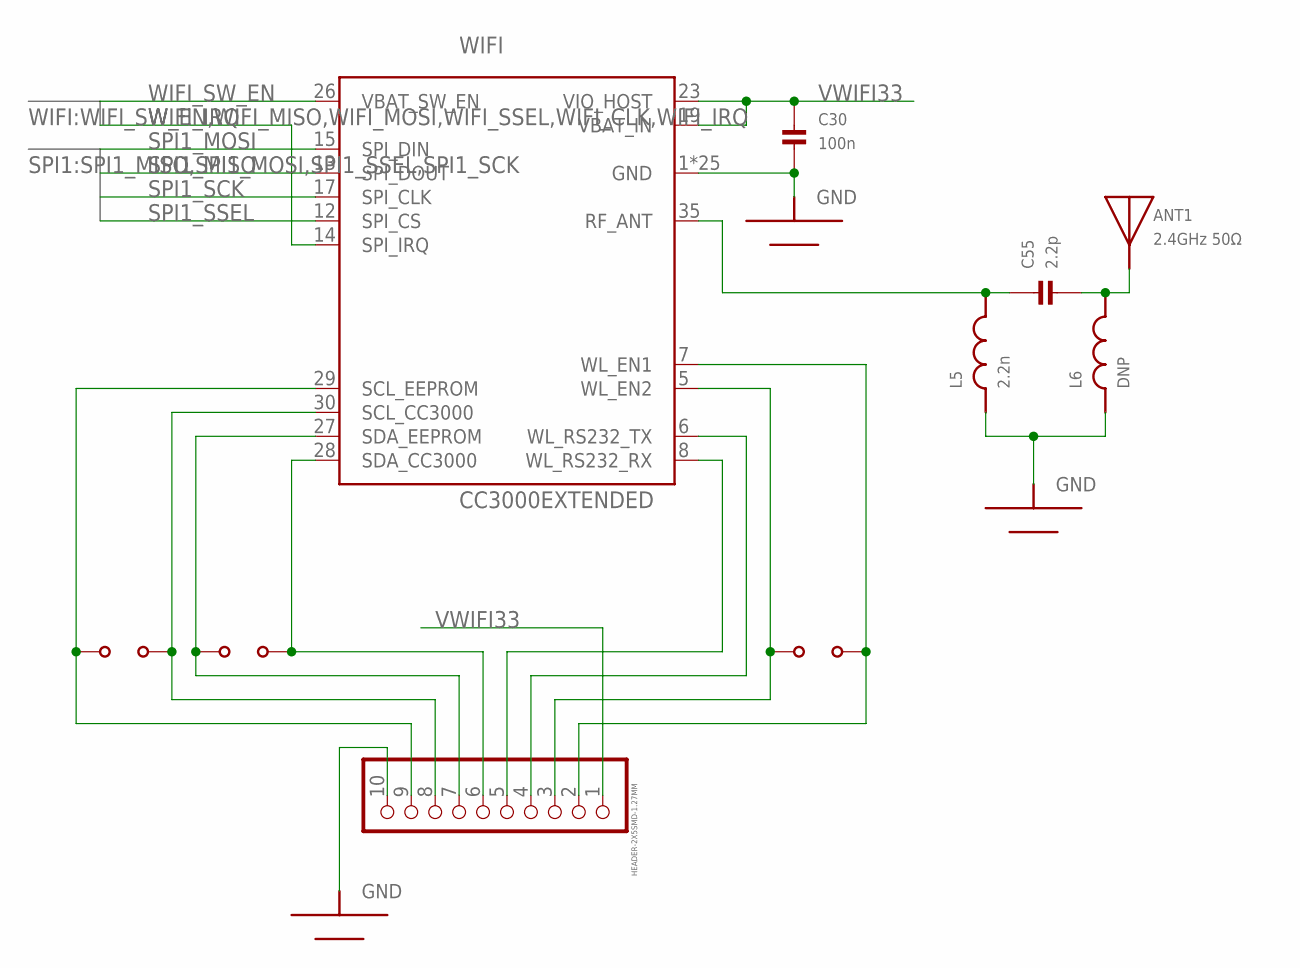
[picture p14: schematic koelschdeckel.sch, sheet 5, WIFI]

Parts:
ANT1: 2.4GHz 50Ω; 1206_MINIMELF_COMBO
C30: 100n; 0603
C55: 2.2p; 0402
CC_DEBUG: HEADER-2X5SMD-1.27MM; 2X05_SMT
L5: 2.2n; 0402
L6: DNP; 0402
SCL: JUMPERSOLDER_CLOSED; 0603_SOLDERJUMPER_CLOSED
SDA: JUMPERSOLDER_CLOSED; 0603_SOLDERJUMPER_CLOSED
WIFI: CC3000EXTENDED; CC3000-EXT
WL_EN: JUMPERSOLDER_CLOSED; 0603_SOLDERJUMPER_CLOSED

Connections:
GND: C30.2, CC_DEBUG.10, L5.P$1 (1), L6.P$1 (1), WIFI.1 (GND), WIFI.9 (GND), WIFI.10 (GND), WIFI.11 (GND), WIFI.16 (GND), WIFI.18 (GND), WIFI.20 (GND), WIFI.21 (GND), WIFI.22 (GND), WIFI.25 (GND), WIFI.31 (GND), WIFI.32 (GND), WIFI.33 (GND), WIFI.34 (GND), WIFI.36 (GND), WIFI.37 (GND), WIFI.38 (GND), WIFI.39 (GND), WIFI.40 (GND), WIFI.41 (GND), WIFI.42 (GND), WIFI.43 (GND), WIFI.44 (GND), WIFI.45 (GND), WIFI.46 (GND); also elsewhere on the board
SPI1_MISO: WIFI.13 (SPI_DOUT); also elsewhere on the board
SPI1_MOSI: WIFI.15 (SPI_DIN); also elsewhere on the board
SPI1_SCK: WIFI.17 (SPI_CLK); also elsewhere on the board
SPI1_SSEL: WIFI.12 (SPI_CS); also elsewhere on the board
VWIFI33: C30.1, CC_DEBUG.1, WIFI.19 (VBAT_IN), WIFI.23 (VIO_HOST); also elsewhere on the board
WIFI_ANT: ANT1.1, C55.P$2, L6.P$2 (2)
WIFI_ANT_UNBAL: C55.P$1, L5.P$2 (2), WIFI.35 (RF_ANT)
WIFI_IRQ: WIFI.14 (SPI_IRQ); also elsewhere on the board
WIFI_SCL_CC3000: CC_DEBUG.8, SCL.1, WIFI.30 (SCL_CC3000)
WIFI_SCL_EEPROM: CC_DEBUG.9, SCL.2, WIFI.29 (SCL_EEPROM)
WIFI_SDA_CC3000: CC_DEBUG.6, SDA.1, WIFI.28 (SDA_CC3000)
WIFI_SDA_EEPROM: CC_DEBUG.7, SDA.2, WIFI.27 (SDA_EEPROM)
WIFI_SW_EN: WIFI.26 (VBAT_SW_EN); also elsewhere on the board
WL_EN1: CC_DEBUG.2, WIFI.7 (WL_EN1), WL_EN.1
WL_EN2: CC_DEBUG.3, WIFI.5 (WL_EN2), WL_EN.2
WL_RS232_RX: CC_DEBUG.5, WIFI.8 (WL_RS232_RX)
WL_RS232_TX: CC_DEBUG.4, WIFI.6 (WL_RS232_TX)

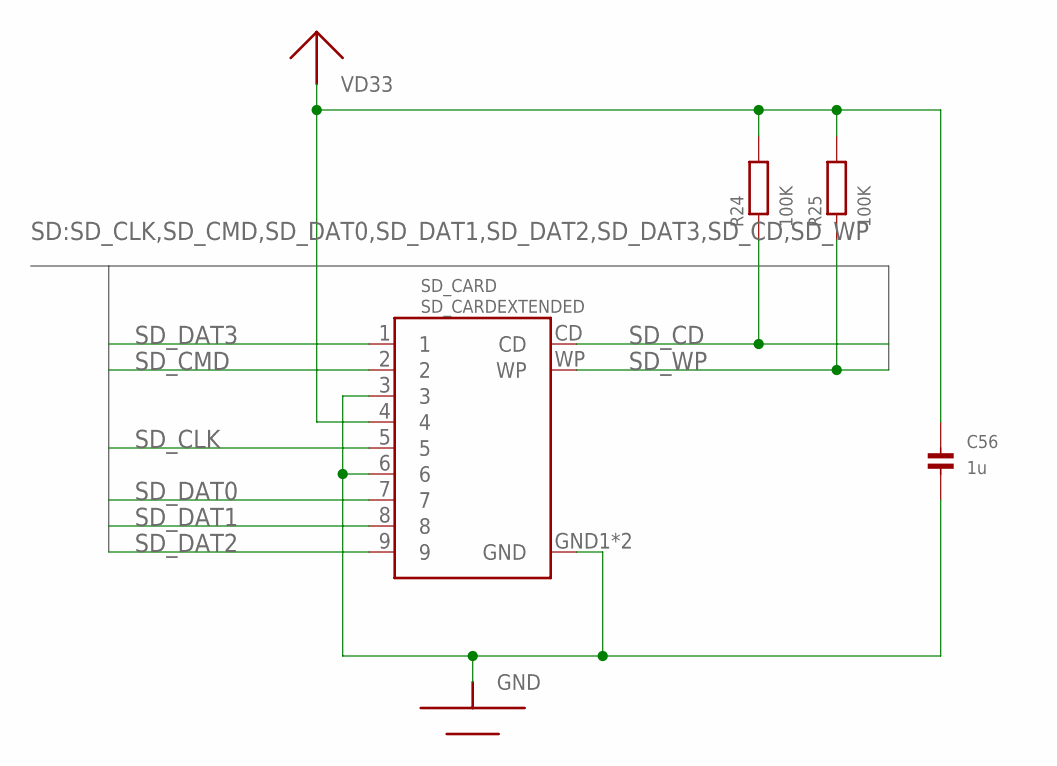
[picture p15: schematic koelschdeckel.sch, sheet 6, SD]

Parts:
C56: 1u; 0603
R24, R25: 100K; 0603
SD_CARD: SD_CARDEXTENDED; AMPHENO_101_00313_EXT_PADS

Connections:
GND: C56.2, SD_CARD.3, SD_CARD.6, SD_CARD.GND1 (GND), SD_CARD.GND2 (GND); also elsewhere on the board
SD_CD: R24.1, SD_CARD.CD; also elsewhere on the board
SD_CLK: SD_CARD.5; also elsewhere on the board
SD_CMD: SD_CARD.2; also elsewhere on the board
SD_DAT0: SD_CARD.7; also elsewhere on the board
SD_DAT1: SD_CARD.8; also elsewhere on the board
SD_DAT2: SD_CARD.9; also elsewhere on the board
SD_DAT3: SD_CARD.1; also elsewhere on the board
SD_WP: R25.1, SD_CARD.WP; also elsewhere on the board
VD33: C56.1, R24.2, R25.2, SD_CARD.4; also elsewhere on the board

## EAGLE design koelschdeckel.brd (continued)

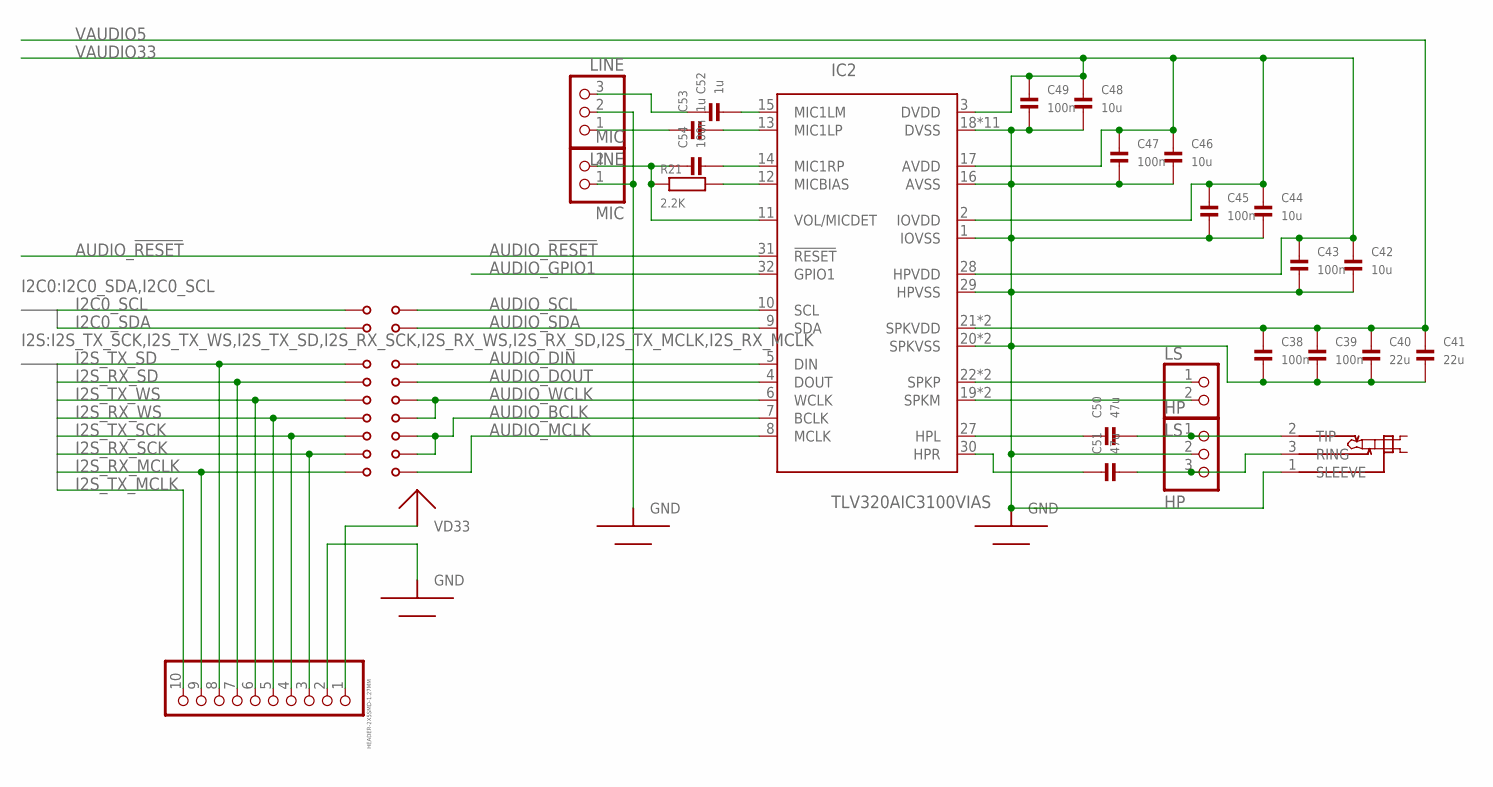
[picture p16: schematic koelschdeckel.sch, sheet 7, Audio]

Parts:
A_SCL: JUMPERSOLDER_CLOSED; 0603_SOLDERJUMPER_CLOSED
A_SDA: JUMPERSOLDER_CLOSED; 0603_SOLDERJUMPER_CLOSED
C38, C39, C43, C45, C47, C49, C54: 100n; 0603
C40, C41: 22u; 0603
C42, C44, C46, C48: 10u; 0603
C50, C51: 47u; 0805
C52, C53: 1u; 0603
HEADPHONE: AUDIOJACK-STEREO-3PCUI_SJ_3523; CUI_SJ_3523_SMT
HP: HP; 1X03_ROUND
I2S: HEADER-2X5SMD-1.27MM; 2X05_SMT
IC2: TLV320AIC3100VIAS; QFN32-0.5-EP-VIAS
LINE: LINE; 1X03_ROUND
LS: LS; 1X02_ROUND
MCLK: JUMPERSOLDER_CLOSED; 0603_SOLDERJUMPER_CLOSED
MIC: MIC; 1X02_ROUND
R21: 2.2K; 0603
RX_SCK: JUMPERSOLDER_CLOSED; 0603_SOLDERJUMPER_CLOSED
RX_SD: JUMPERSOLDER_CLOSED; 0603_SOLDERJUMPER_CLOSED
RX_WS: JUMPERSOLDER_CLOSED; 0603_SOLDERJUMPER_CLOSED
TX_SCK: JUMPERSOLDER_CLOSED; 0603_SOLDERJUMPER_CLOSED
TX_SD: JUMPERSOLDER_CLOSED; 0603_SOLDERJUMPER_CLOSED
TX_WS: JUMPERSOLDER_CLOSED; 0603_SOLDERJUMPER_CLOSED

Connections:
AUDIO_!RESET: IC2.31 (!RESET); also elsewhere on the board
AUDIO_BCLK: IC2.7 (BCLK), RX_SCK.2, TX_SCK.2
AUDIO_DIN: IC2.5 (DIN), TX_SD.2
AUDIO_DOUT: IC2.4 (DOUT), RX_SD.2
AUDIO_GPIO1: IC2.32 (GPIO1)
AUDIO_MCLK: IC2.8 (MCLK), MCLK.2
AUDIO_SCL: A_SCL.2, IC2.10 (SCL)
AUDIO_SDA: A_SDA.2, IC2.9 (SDA)
AUDIO_WCLK: IC2.6 (WCLK), RX_WS.2, TX_WS.2
GND: C38.2, C39.2, C40.2, C41.2, C42.2, C43.2, C44.2, C45.2, C46.2, C47.2, C48.2, C49.2, HEADPHONE.1 (SLEEVE), HP.2, I2S.2, IC2.1 (IOVSS), IC2.16 (AVSS), IC2.18 (DVSS), IC2.20 (SPKVSS), IC2.25 (SPKVSS), IC2.29 (HPVSS), IC2.PAD (DVSS), IC2.VIA1 (DVSS), IC2.VIA2 (DVSS), IC2.VIA3 (DVSS), IC2.VIA4 (DVSS), IC2.VIA5 (DVSS), IC2.VIA6 (DVSS), IC2.VIA7 (DVSS), IC2.VIA8 (DVSS), IC2.VIA9 (DVSS), LINE.2, MIC.1; also elsewhere on the board
HPL: C50.1, IC2.27 (HPL)
HPR: C51.1, IC2.30 (HPR)
HP_L: C50.2, HEADPHONE.2 (TIP), HP.1
HP_R: C51.2, HEADPHONE.3 (RING), HP.3
I2C0_SCL: A_SCL.1; also elsewhere on the board
I2C0_SDA: A_SDA.1; also elsewhere on the board
I2S_RX_MCLK: I2S.9, MCLK.1; also elsewhere on the board
I2S_RX_SCK: I2S.3, RX_SCK.1; also elsewhere on the board
I2S_RX_SD: I2S.7, RX_SD.1; also elsewhere on the board
I2S_RX_WS: I2S.5, RX_WS.1; also elsewhere on the board
I2S_TX_MCLK: I2S.10; also elsewhere on the board
I2S_TX_SCK: I2S.4, TX_SCK.1; also elsewhere on the board
I2S_TX_SD: I2S.8, TX_SD.1; also elsewhere on the board
I2S_TX_WS: I2S.6, TX_WS.1; also elsewhere on the board
LINEIN1: C52.1, LINE.3
LINEIN2: C53.1, LINE.1
MIC1LM: C52.2, IC2.15 (MIC1LM)
MIC1LP: C53.2, IC2.13 (MIC1LP)
MIC1RP: C54.2, IC2.14 (MIC1RP)
MICBIAS: IC2.12 (MICBIAS), R21.2
unnamed: C54.1, IC2.11 (VOL/MICDET), MIC.2, R21.1
SPKM: IC2.19 (SPKM), IC2.23 (SPKM), LS.2
SPKP: IC2.22 (SPKP), IC2.26 (SPKP), LS.1
VAUDIO5: C38.1, C39.1, C40.1, C41.1, IC2.21 (SPKVDD), IC2.24 (SPKVDD); also elsewhere on the board
VAUDIO33: C42.1, C43.1, C44.1, C45.1, C46.1, C47.1, C48.1, C49.1, IC2.2 (IOVDD), IC2.3 (DVDD), IC2.17 (AVDD), IC2.28 (HPVDD); also elsewhere on the board
VD33: I2S.1; also elsewhere on the board

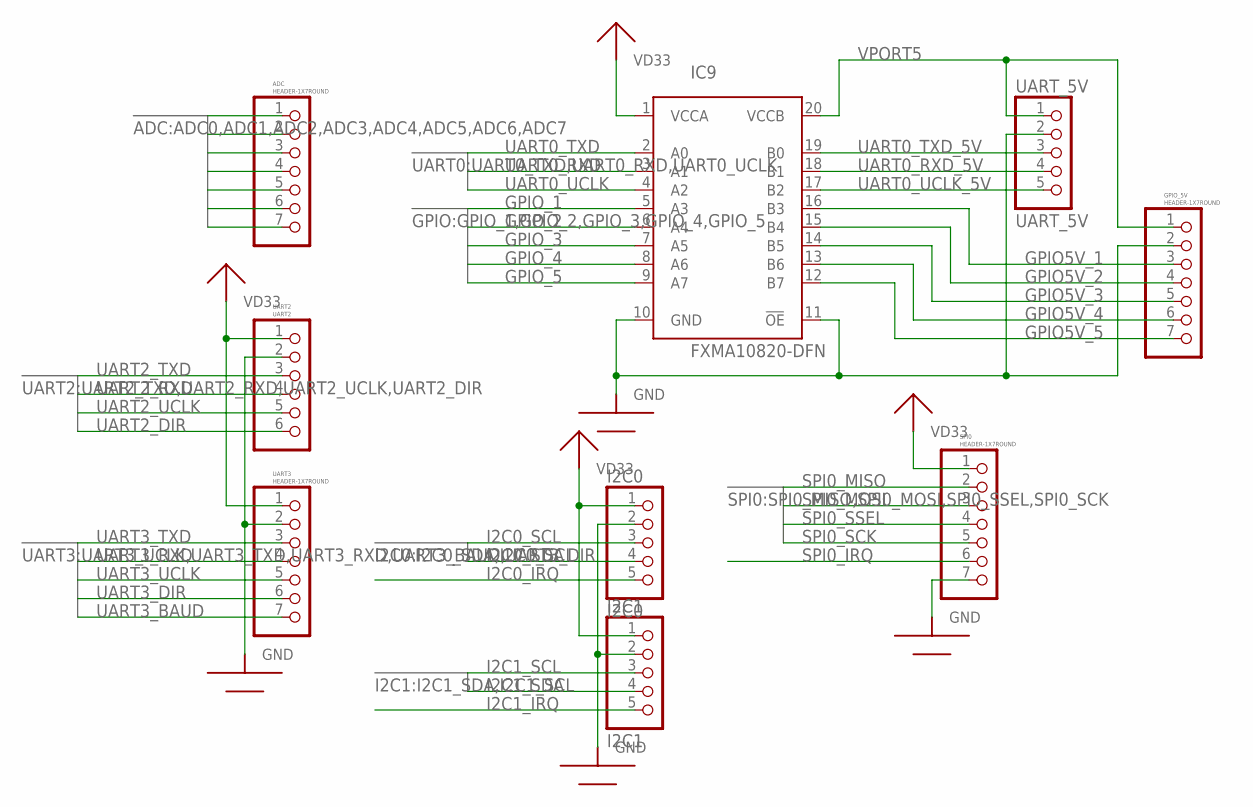
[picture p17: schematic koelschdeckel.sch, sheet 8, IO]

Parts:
ADC: HEADER-1X7ROUND; 1X07_ROUND
GPIO_5V: HEADER-1X7ROUND; 1X07_ROUND
I2C0: I2C0; 1X05_ROUND
I2C1: I2C1; 1X05_ROUND
IC9: FXMA10820-DFN; FXMA108
SPI0: HEADER-1X7ROUND; 1X07_ROUND
UART2: UART2; 1X06_ROUND
UART3: HEADER-1X7ROUND; 1X07_ROUND
UART_5V: UART_5V; 1X05_ROUND

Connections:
ADC0: ADC.1; also elsewhere on the board
ADC1: ADC.2; also elsewhere on the board
ADC2: ADC.3; also elsewhere on the board
ADC3: ADC.4; also elsewhere on the board
ADC4: ADC.5; also elsewhere on the board
ADC5: ADC.6; also elsewhere on the board
ADC6: ADC.7; also elsewhere on the board
GND: GPIO_5V.2, I2C0.2, I2C1.2, IC9.10 (GND), IC9.11 (!OE), SPI0.7, UART2.2, UART3.2, UART_5V.2; also elsewhere on the board
GPIO5V_1: GPIO_5V.3, IC9.16 (B3)
GPIO5V_2: GPIO_5V.4, IC9.15 (B4)
GPIO5V_3: GPIO_5V.5, IC9.14 (B5)
GPIO5V_4: GPIO_5V.6, IC9.13 (B6)
GPIO5V_5: GPIO_5V.7, IC9.12 (B7)
GPIO_1: IC9.5 (A3); also elsewhere on the board
GPIO_2: IC9.6 (A4); also elsewhere on the board
GPIO_3: IC9.7 (A5); also elsewhere on the board
GPIO_4: IC9.8 (A6); also elsewhere on the board
GPIO_5: IC9.9 (A7); also elsewhere on the board
I2C0_IRQ: I2C0.5; also elsewhere on the board
I2C0_SCL: I2C0.3; also elsewhere on the board
I2C0_SDA: I2C0.4; also elsewhere on the board
I2C1_IRQ: I2C1.5; also elsewhere on the board
I2C1_SCL: I2C1.3; also elsewhere on the board
I2C1_SDA: I2C1.4; also elsewhere on the board
SPI0_IRQ: SPI0.6; also elsewhere on the board
SPI0_MISO: SPI0.2; also elsewhere on the board
SPI0_MOSI: SPI0.3; also elsewhere on the board
SPI0_SCK: SPI0.5; also elsewhere on the board
SPI0_SSEL: SPI0.4; also elsewhere on the board
UART0_RXD: IC9.3 (A1); also elsewhere on the board
UART0_RXD_5V: IC9.18 (B1), UART_5V.4
UART0_TXD: IC9.2 (A0); also elsewhere on the board
UART0_TXD_5V: IC9.19 (B0), UART_5V.3
UART0_UCLK: IC9.4 (A2); also elsewhere on the board
UART0_UCLK_5V: IC9.17 (B2), UART_5V.5
UART2_DIR: UART2.6; also elsewhere on the board
UART2_RXD: UART2.4; also elsewhere on the board
UART2_TXD: UART2.3; also elsewhere on the board
UART2_UCLK: UART2.5; also elsewhere on the board
UART3_BAUD: UART3.7; also elsewhere on the board
UART3_DIR: UART3.6; also elsewhere on the board
UART3_RXD: UART3.4; also elsewhere on the board
UART3_TXD: UART3.3; also elsewhere on the board
UART3_UCLK: UART3.5; also elsewhere on the board
VD33: I2C0.1, I2C1.1, IC9.1 (VCCA), SPI0.1, UART2.1, UART3.1; also elsewhere on the board
VPORT5: GPIO_5V.1, IC9.20 (VCCB), UART_5V.1; also elsewhere on the board

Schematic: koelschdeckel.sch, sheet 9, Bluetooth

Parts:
ANT2: 2.4GHz 50Ω; 1206_MINIMELF_COMBO
BAL1: BALUNWLCSP; ST_BAL_WLCSP
C1: 1n; 0402
C61: 47n; 0402
C62, C63, C64: 100n; 0402
C66, C67: 12p; 0402
C68, C69: 9p; 0402
C72: 2.2n; 0402
MCU1: NRF51822QFN48; QFN48_EP
NRF_DEBUG: HEADER-2X5SMD-1.27MM; 2X05_SMT
R34: 100K; 0603
X3: 32768; 1206_MINIMELF_COMBO
X5: 16MHz; CRYSTAL25X20

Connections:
BT_ANT: ANT2.1, BAL1.SE (UNBAL)
BT_ANT1: BAL1.DIFF2 (BAL2), MCU1.31 (ANT1)
BT_ANT2: BAL1.DIFF1 (BAL1), MCU1.32 (ANT2)
BT_DEC1: C62.P$1, MCU1.39 (DEC1)
BT_DEC2: C61.P$1, MCU1.29 (DEC2)
BT_VDD_PA: BAL1.VCC (DC), C72.P$2, MCU1.30 (VDD_PA)
BT_XC1: C67.P$1, MCU1.37 (XC1), X5.1
BT_XC2: C66.P$1, MCU1.38 (XC2), X5.3 (2)
BT_XL1: C69.P$2, MCU1.46 (P0.27), X3.1
BT_XL2: C68.P$2, MCU1.45 (P0.26), X3.2
GND: BAL1.GND, C1.P$2, C61.P$2, C62.P$2, C63.P$2, C64.P$2, C66.P$2, C67.P$2, C68.P$1, C69.P$1, C72.P$1, MCU1.13 (VSS), MCU1.33 (VSS), MCU1.34 (VSS), MCU1.PAD (VSS), NRF_DEBUG.3, NRF_DEBUG.5, NRF_DEBUG.7, NRF_DEBUG.9, R34.1, X5.2 (GND), X5.4 (GND); also elsewhere on the board
NRF_SWDCLK: MCU1.24 (SWDCLK), NRF_DEBUG.4, R34.2; also elsewhere on the board
NRF_SWDIO: MCU1.23 (SWDIO/NRESET), NRF_DEBUG.2; also elsewhere on the board
UART1_CTS: MCU1.7 (P0.03); also elsewhere on the board
UART1_RTS: MCU1.6 (P0.02); also elsewhere on the board
UART1_RXD: MCU1.5 (P0.01); also elsewhere on the board
UART1_TXD: MCU1.4 (P0.00); also elsewhere on the board
VD33: C1.P$1, C63.P$1, C64.P$1, MCU1.1 (VDD), MCU1.12 (VDD), MCU1.35 (AVDD), MCU1.36 (AVDD), NRF_DEBUG.1; also elsewhere on the board

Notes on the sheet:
Note: R34 only needed for first revision of NRF51822. DNP for Rev. 2 and up.

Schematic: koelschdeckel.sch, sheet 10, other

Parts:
LOGO2, LOGO3, LOGO4: LOGOKRONE; LOGO-KRONE

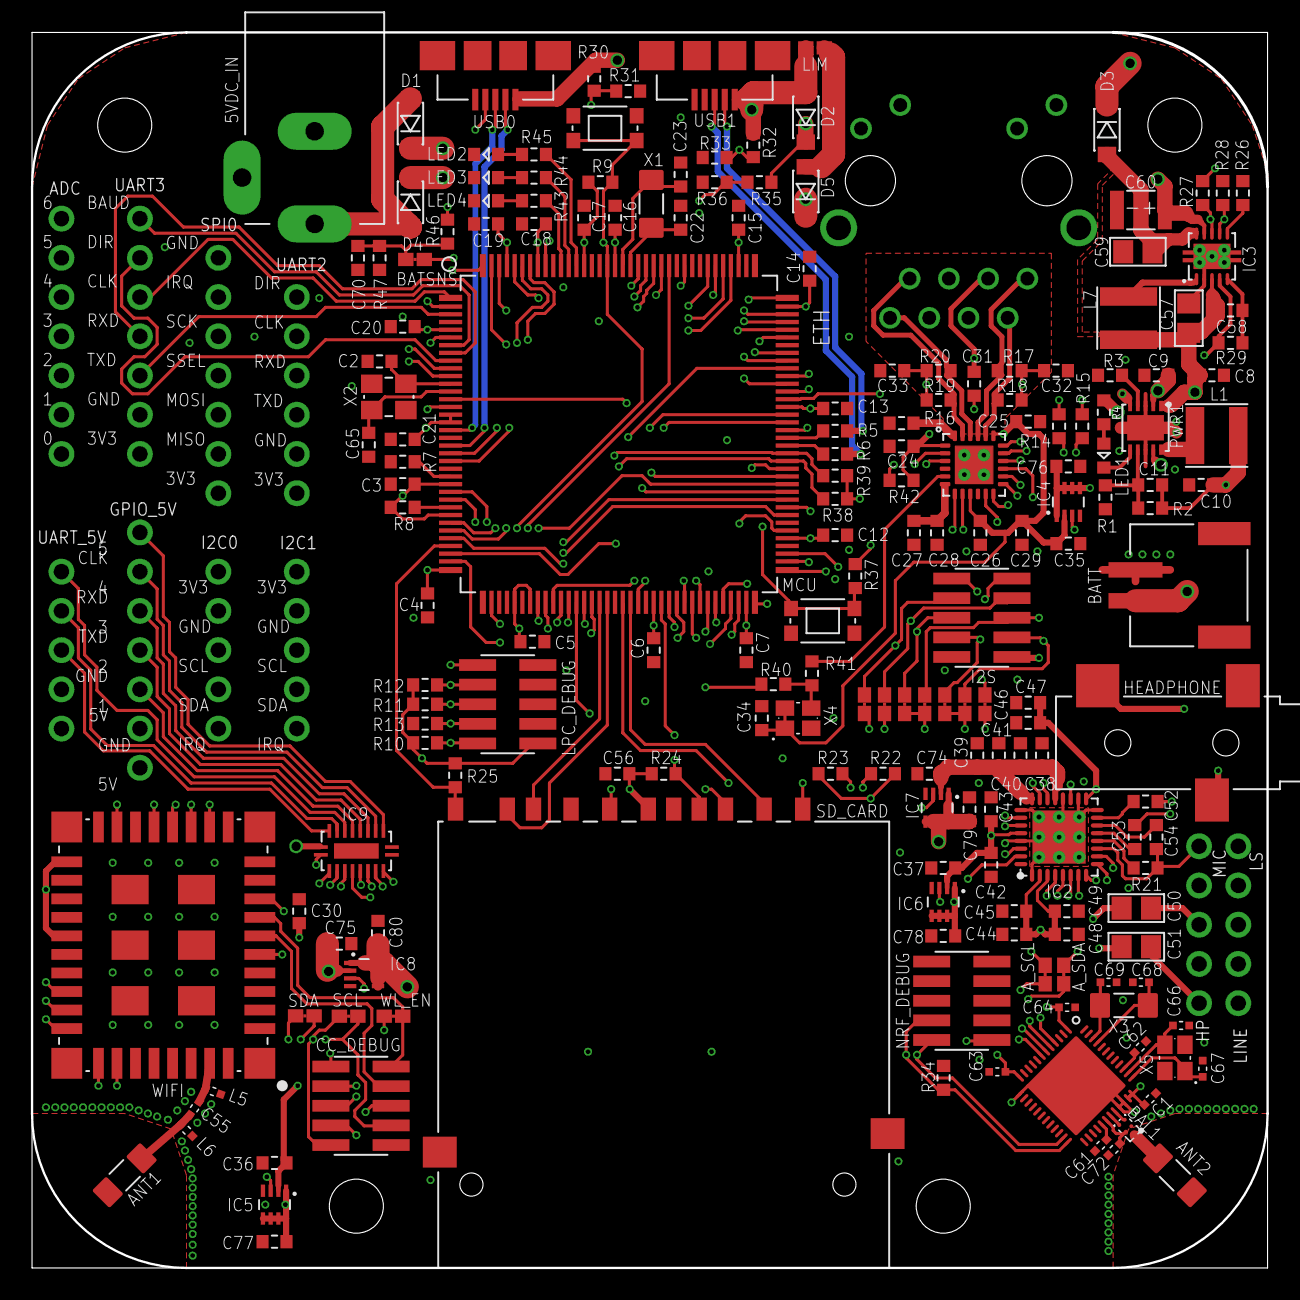
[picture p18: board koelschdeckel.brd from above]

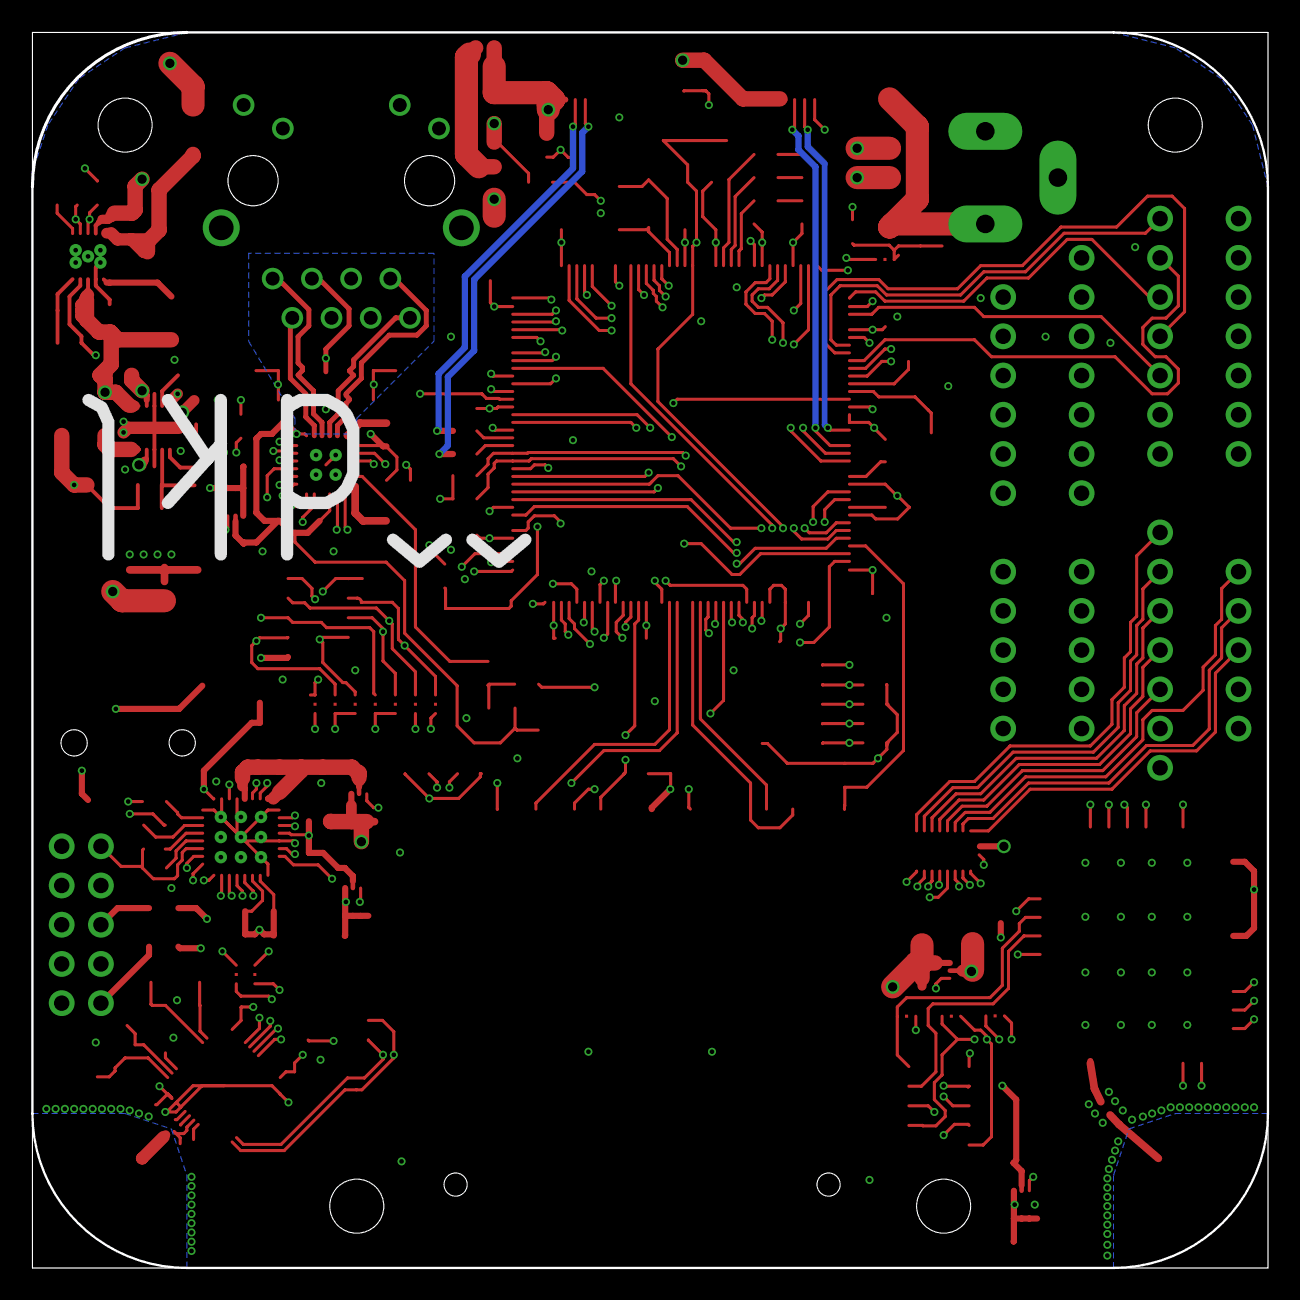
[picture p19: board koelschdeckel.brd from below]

Board: 4 copper layers, 80.0 x 80.0 mm, 201 parts (3 on the bottom side), 193 nets.

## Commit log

2014-01-14 initial version
    [sparrow.brd, sparrow.sch]
2014-01-28 Further work
    [sparrow.brd, sparrow.sch]
2014-03-12 positioned and connected headers
    [sparrow.brd, sparrow.sch]
2014-03-12 layout refinements
    [sparrow.brd, sparrow.sch]
2014-03-14 basic routing finished
    [sparrow.brd, sparrow.sch]
2014-03-14 Silkscreen fixed
    [sparrow.brd, sparrow.sch]
2014-03-25 power routing, added LEDs, several last-minute improvements
    [sparrow.brd, sparrow.sch]
2014-03-25 moved artwork
    [sparrow.brd]
2014-04-16 renamed library everykey
    [sparrow.brd, sparrow.sch]
2014-04-16 approved sup/out erc warning
    [sparrow.sch]
2014-04-16 phy capacitors
    [sparrow.brd, sparrow.sch]
2014-04-16 moved caps
    [sparrow.sch]
2014-04-16 Added battery sensing
    [sparrow.brd, sparrow.sch]
2014-04-17 Final impedance touchup
    [sparrow.brd, sparrow.sch]
2014-04-17 Last library update, DRC fixes
    [sparrow.brd, sparrow.sch]
2014-05-04 Updated values
    [sparrow.brd, sparrow.sch]
2014-05-05 value tuning
    [sparrow.brd, sparrow.sch]
2015-04-02 Fine tuning
    [sparrow.brd, sparrow.sch]
2015-04-02 added pdf renamed to koelschdeckel
    [koelschdeckel.brd, koelschdeckel.sch]
2015-04-02 added BOM
    [BOM_Koelschdeckel.csv, BOM_Koelschdeckel.ods, BOM_Koelschdeckel.xlsx]
2015-04-02 moved bom to own directory
    [BOM_Koelschdeckel.csv, BOM_Koelschdeckel.ods, BOM_Koelschdeckel.xlsx]
